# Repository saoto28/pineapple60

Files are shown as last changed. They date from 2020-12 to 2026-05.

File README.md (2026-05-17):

# pineapple60
ergonomic keyboard with Trackpoint

The purposes of this project.
- Install it in ThinkPad

## pineapple-F
Pinapple-Fold, Foldable ergonomic keyboard  
[mockup video on twitter](https://x.com/saoto28/status/2055436990498451473)

## pineapple-D
Pineapple-Deep, under consideration

## p60P
Pineapple60-Popup, installing a Pop-up keyboard on a ThinkPad.  
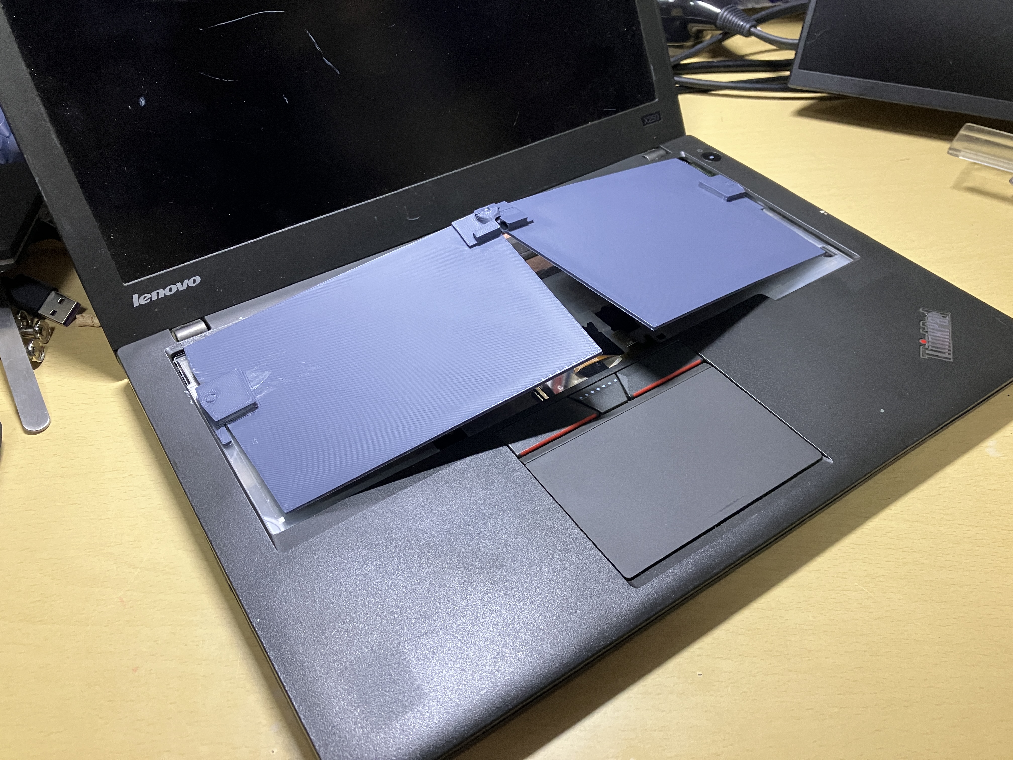
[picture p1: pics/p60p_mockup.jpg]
mockup

[Mockup video](https://youtu.be/z3uHgcyWICA)

## p60C
2026, Pineapple60-Convertible, Three-dimensional ergonomic arrangement and a flat, compact convertible. A patent allowed in Japan.

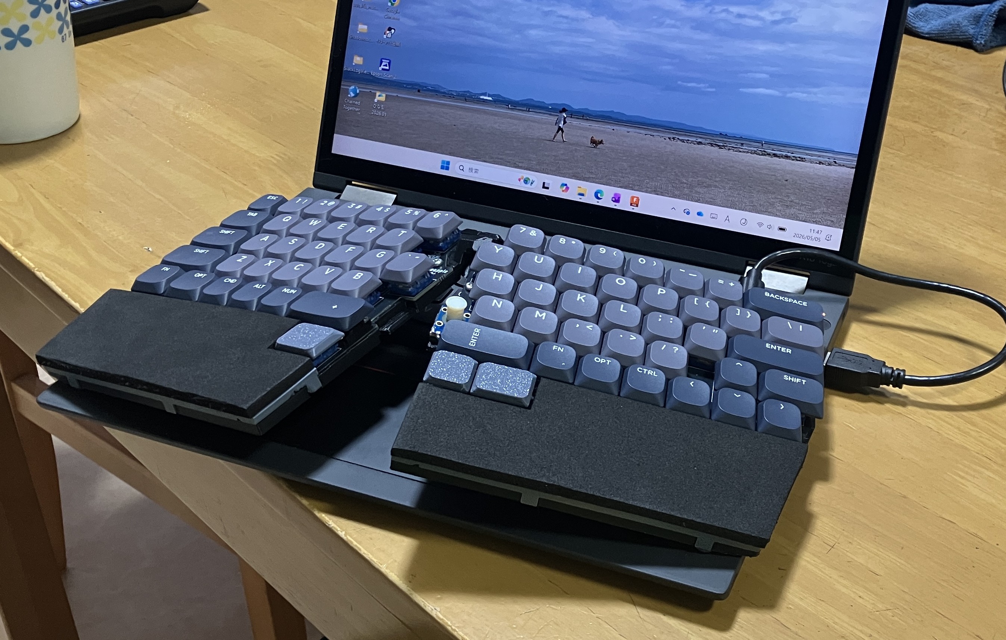
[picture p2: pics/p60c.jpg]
ergonomic mode
1st prototype 
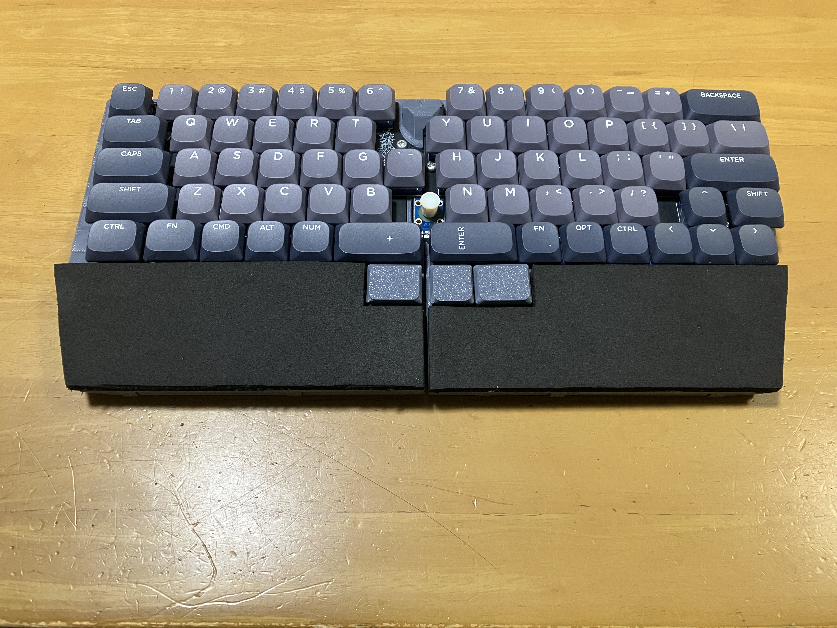
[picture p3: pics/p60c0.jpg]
flat mode

[Video](https://x.com/saoto28/status/2051869687362077159)

Project repository: 
https://github.com/saoto28/pineapple60c.git

## p60S
2025, pineapple60s

Row-Staggered Ergonomic (Alice) keyboard with Kailh PG1316 for installing ThinkPad X13 Gen2

I forgot why it was named "S".

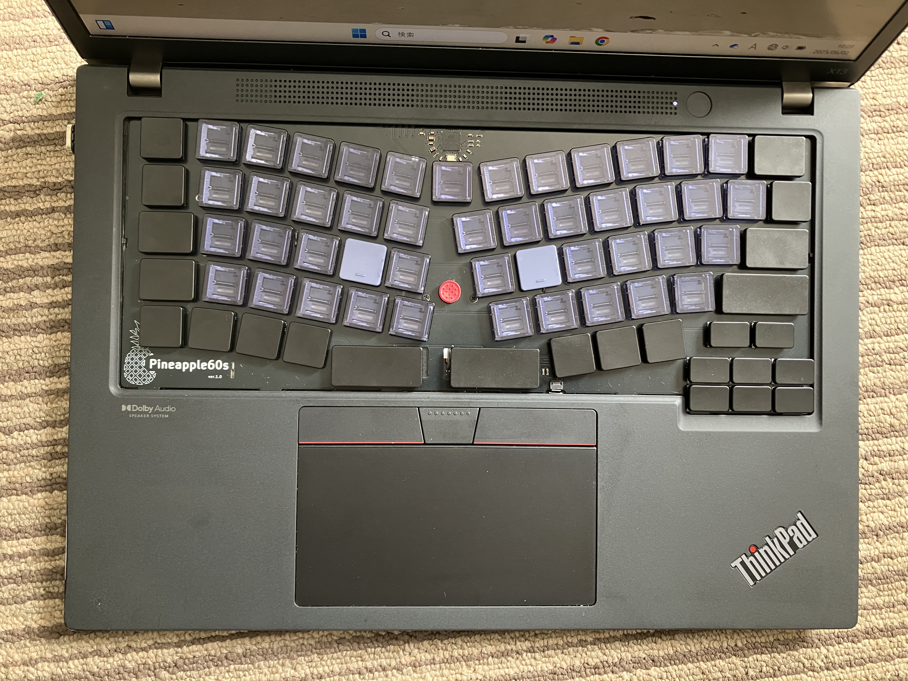
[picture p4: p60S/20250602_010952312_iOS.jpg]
pineapple 60S


For this modification, I chose the target PC for the following reasons:
- It has a Trackpoint
- The keyboard can be easily replaced (the latest ThinkPads are getting difficult)
- The Trackpoint buttons should be on the case, not on the keyboard unit. Otherwise, I would need to attach the buttons to the keyboard I was making.

The following ThinkPads meet the above requirements:
- T440 to T460, and so on
- T460s and T470s
- X13 Gen2 and Gen3

X240 to X270 are also close, but we need to remove the motherboard to remove the keyboard.

Project repository: 
https://github.com/saoto28/pineapple60s.git

How to make (in Japanese): https://note.com/saoto28/n/n716b7ca2e1f9

## p0

Extra edition. Trackpoint module installation.

2021-10 Add the Trackpoint module of ThinkPad X100 on the Microsoft Ergonomic Keyboard.

[How to install the Trackpoint module in the MS ergonomic keyboard](p0/How_to_modify_MS_ergonomic_keyboard.pdf)

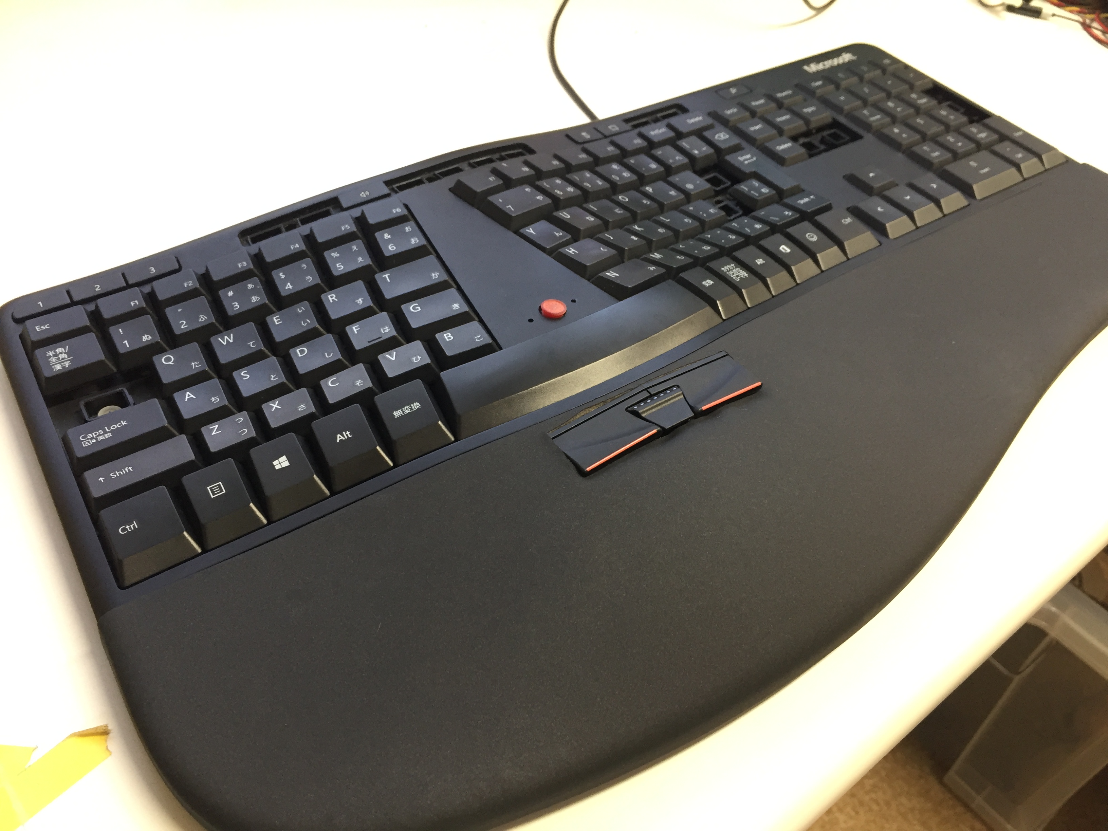
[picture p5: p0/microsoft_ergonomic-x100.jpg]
microsoft_ergonomic


~~## p60X~~

~~Variable key layout board for researching ergonomic keyboard layouts~~

~~< 2021-09 coming soon >~~

## p50V

V-style key layout [board](p50V/README.md)

2021-08 installed on my T470s

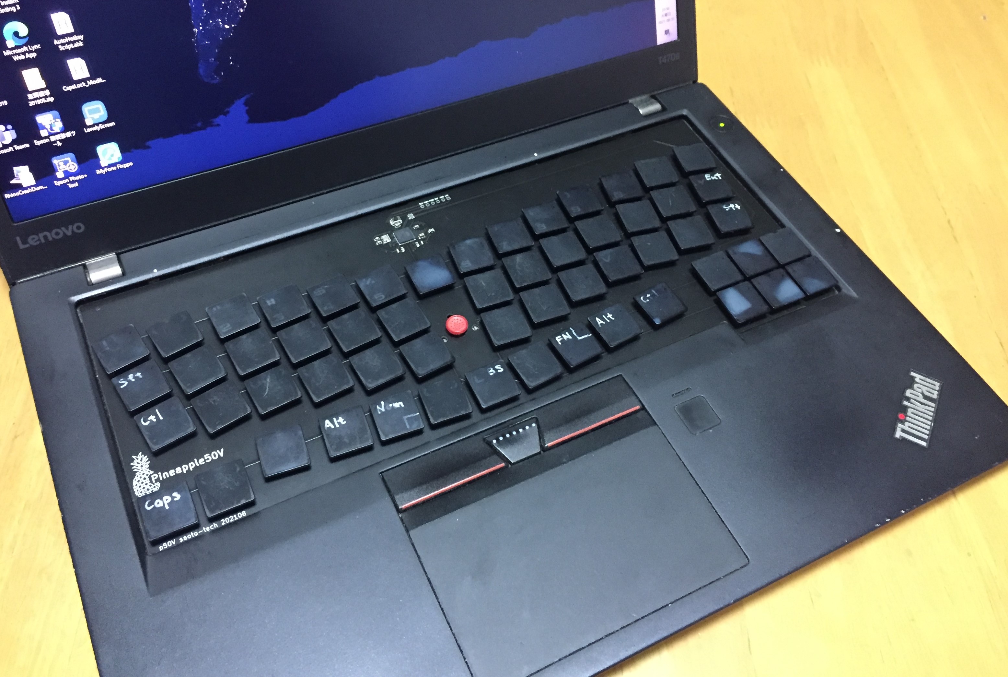
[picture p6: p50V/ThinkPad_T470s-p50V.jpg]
on ThinkPad T470s


## p60-03

third prototype [pcb](p60-03/README.md)

2021-05 p60-03b 

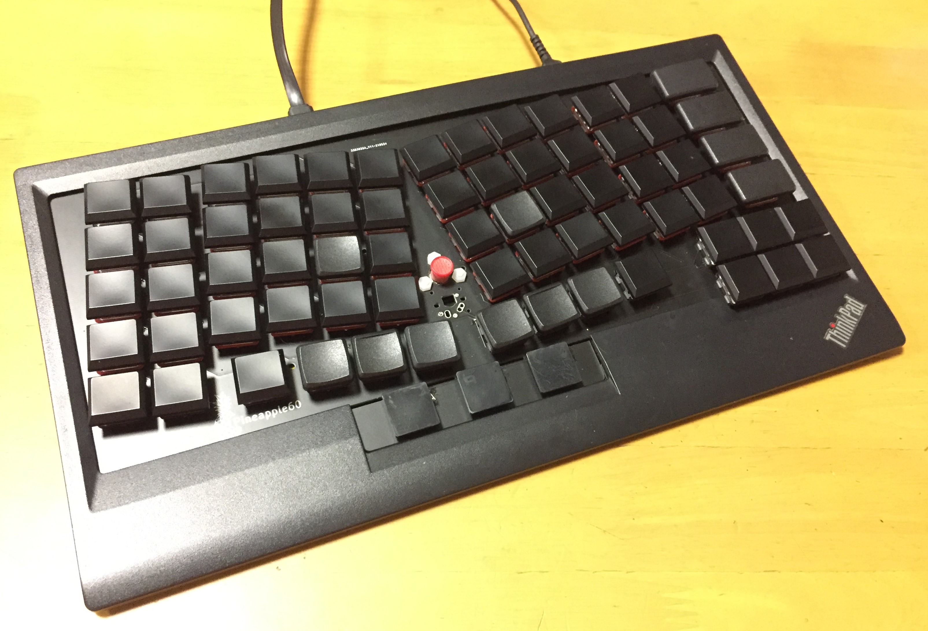
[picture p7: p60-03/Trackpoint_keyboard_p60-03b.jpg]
on Trackpoint keyboard


[how to make the ergonomic Trackpoint keyboard](how_to_make_ergonomic_trackpoint_keyboard.md)

## p4

2021-03 key layout testing [module](p4/README.md)

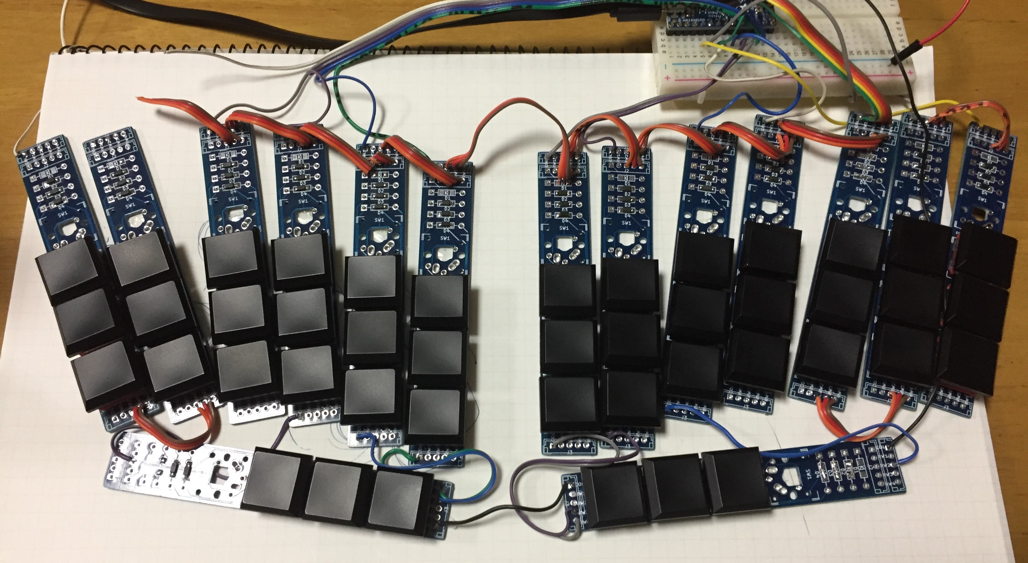
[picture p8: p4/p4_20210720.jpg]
favorite


## p60-02

2020-12 second prototype [pcb](p60-02/README.md)

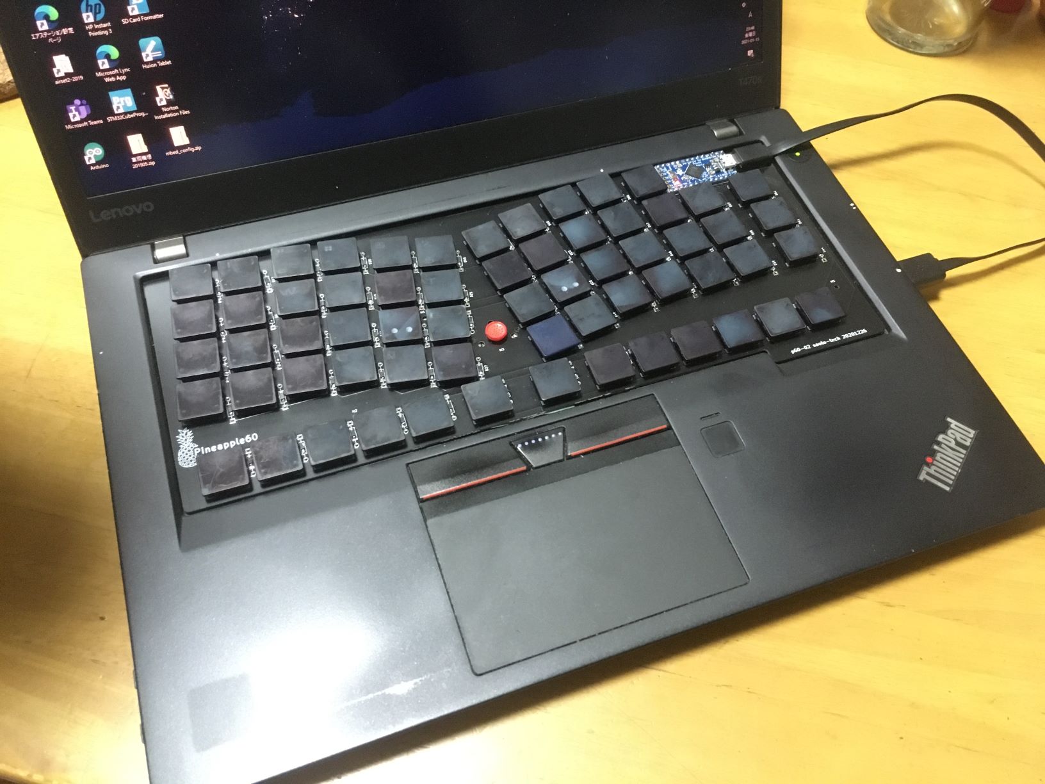
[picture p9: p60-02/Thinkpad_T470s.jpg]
on Thinkpad T470s


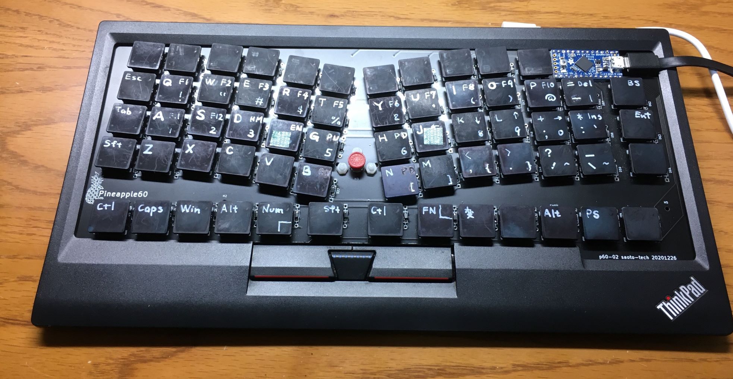
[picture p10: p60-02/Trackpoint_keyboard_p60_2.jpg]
on Trackpoint keyboard


## p60-01

2020-10 first prototype [pcb](p60-01/README.md)

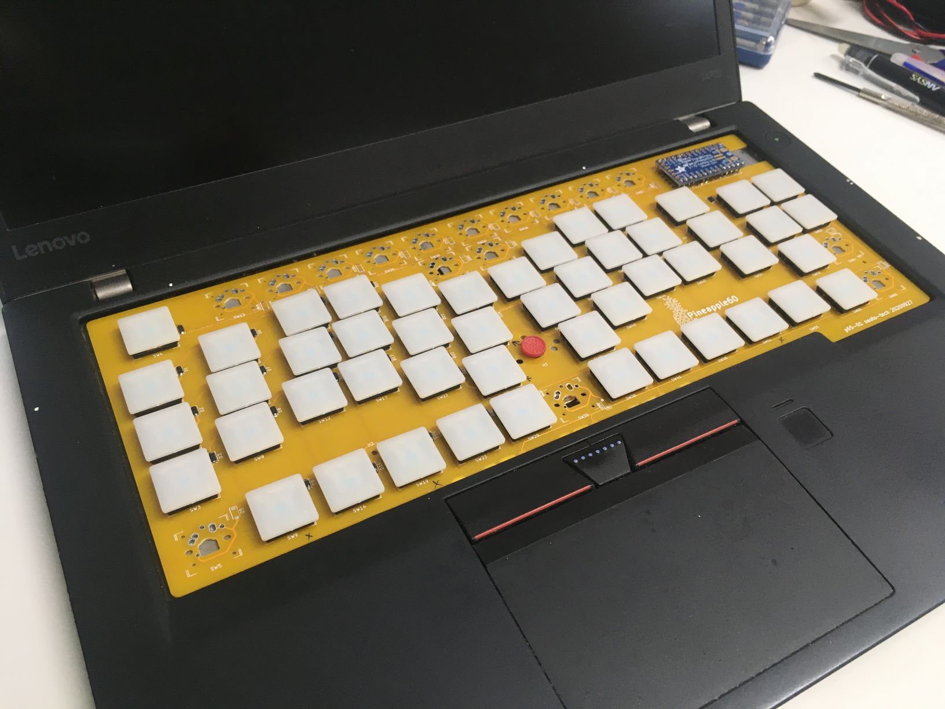
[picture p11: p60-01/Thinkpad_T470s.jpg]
on Thinkpad T470s


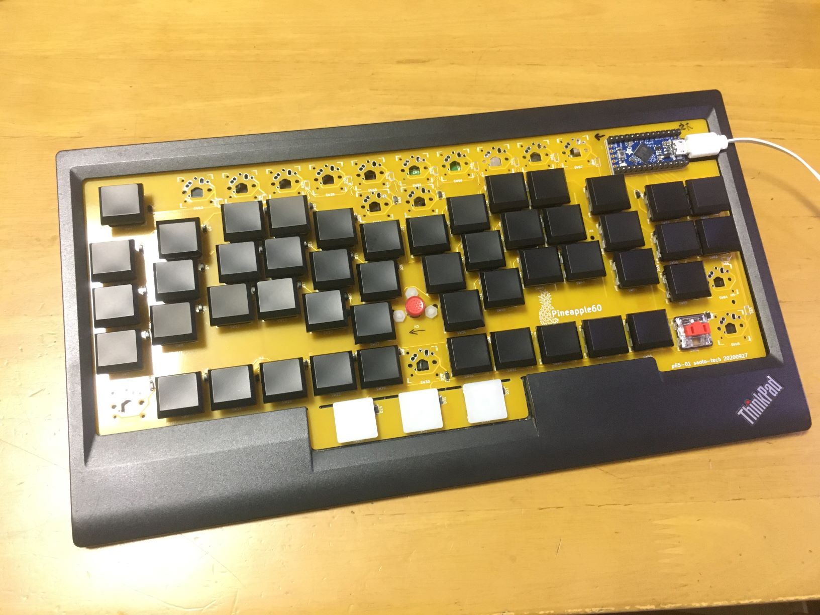
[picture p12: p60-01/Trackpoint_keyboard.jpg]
on Trackpoint keyboard


## pre-pineapple

2020-08 I tried to make an ergonomic keyboard for my ThinkPad T470s, by disassembling and modifying the spare keyboard. But, gave up.

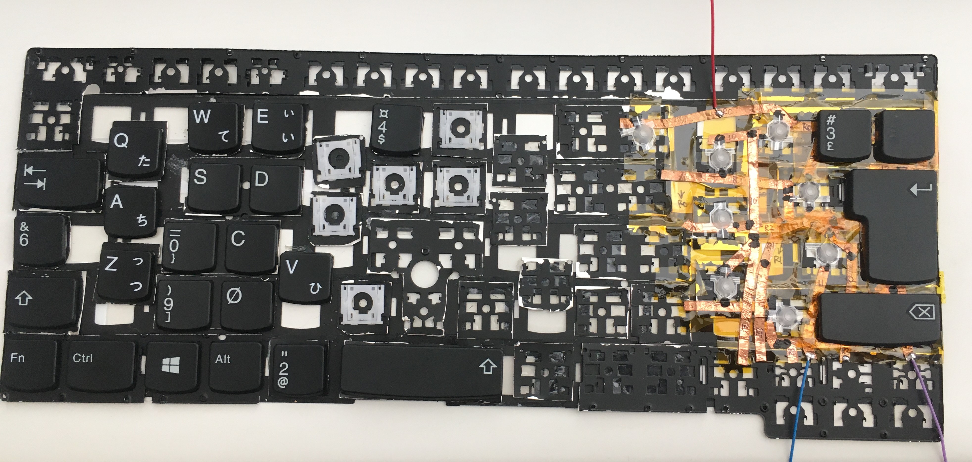
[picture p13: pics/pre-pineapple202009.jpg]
pre-pineapple


## SNS

https://twitter.com/saoto28

https://www.reddit.com/user/saoto28/posts/

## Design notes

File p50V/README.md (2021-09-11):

## p50V
2021-08 V-style layout for ThinkPad T470s

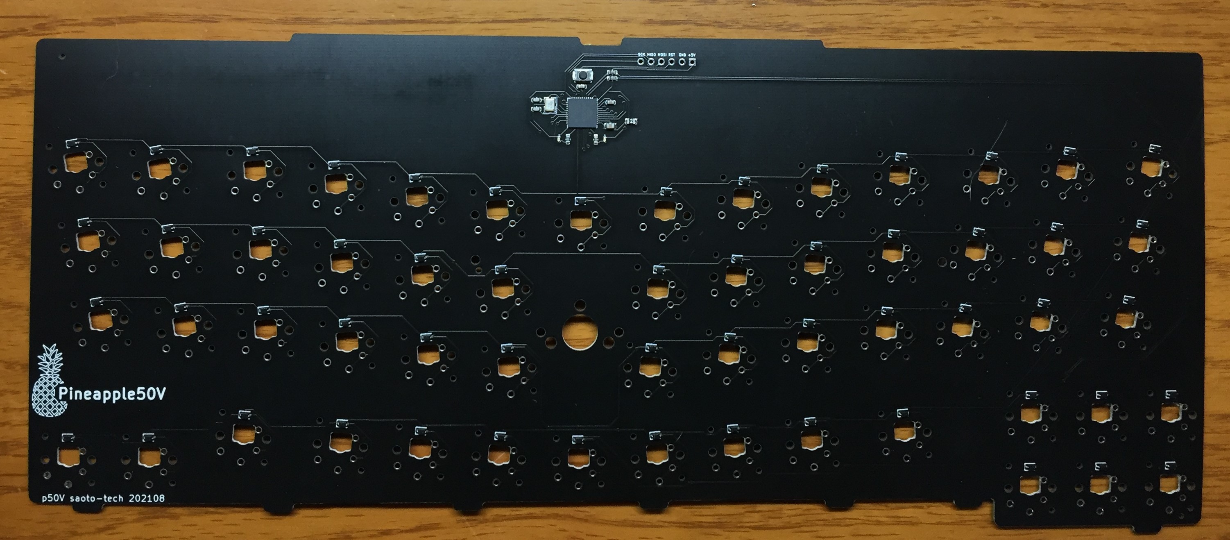
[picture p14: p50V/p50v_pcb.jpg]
PCB


[Schmatic](p50v_sch.pdf)

[PCB](p50v_pcb.pdf)

Features:
- I decided on the V-style layout after testing various layouts with my variable layout keyboard.
- The MCU(Atmega 32u4) is directly installed on the PCB for making it thin. The MCU circuit was referred from the Itsybitsy 32u4.
- Connect the USB line to the port for the smart card reader inside the Thinkpad T470s.

- Give up the top row of key switches because of hitting the frame of the lid. 
- The key switches are the Kailh X-switches that I don't recommend. But, they are the only choice for the laptop.
- Though the key switches are still touching the LCD... I'm using this laptop for mobile.

Issues:
- The Kailh X-switch is not recommended, but no other choice.
- The Kailh X-switches still touch the LCD of the T470s.
- The direction of each key switch was unpopular on Reddit.
- I could flash my app after flashing the bootloader of Itsybitsy, only one time. I'm investigating why.

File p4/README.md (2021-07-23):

## p4
2020-03 key layout testing module
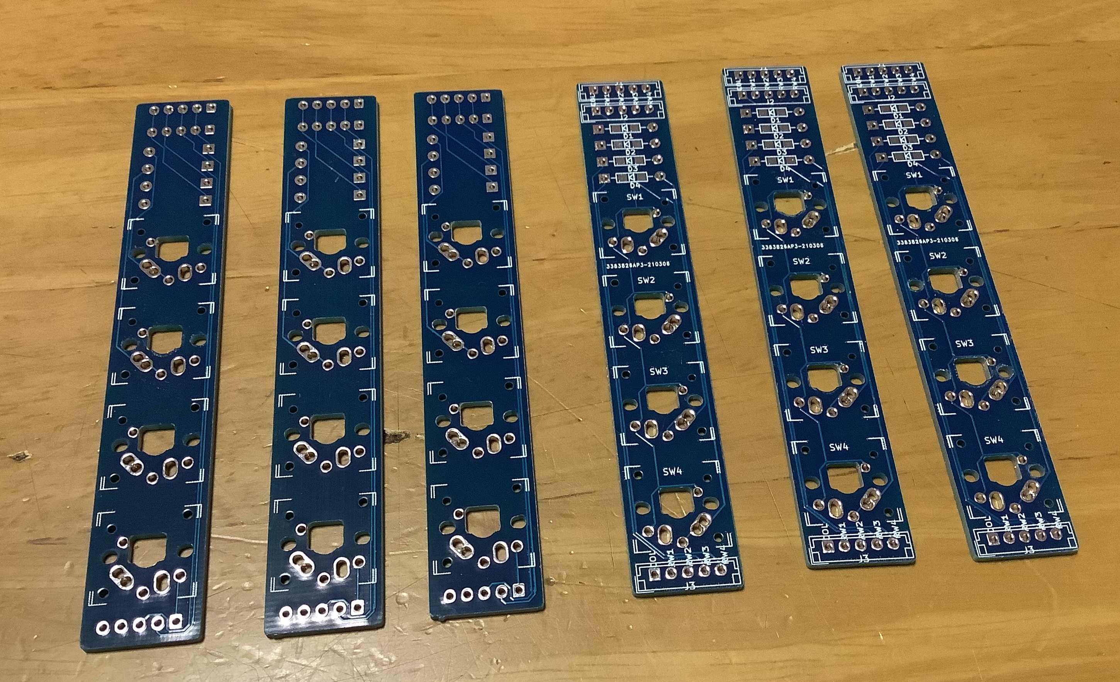
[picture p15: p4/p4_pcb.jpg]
pcb


### X-BOWS like
I feel "T" and "Y" are far from the home position.
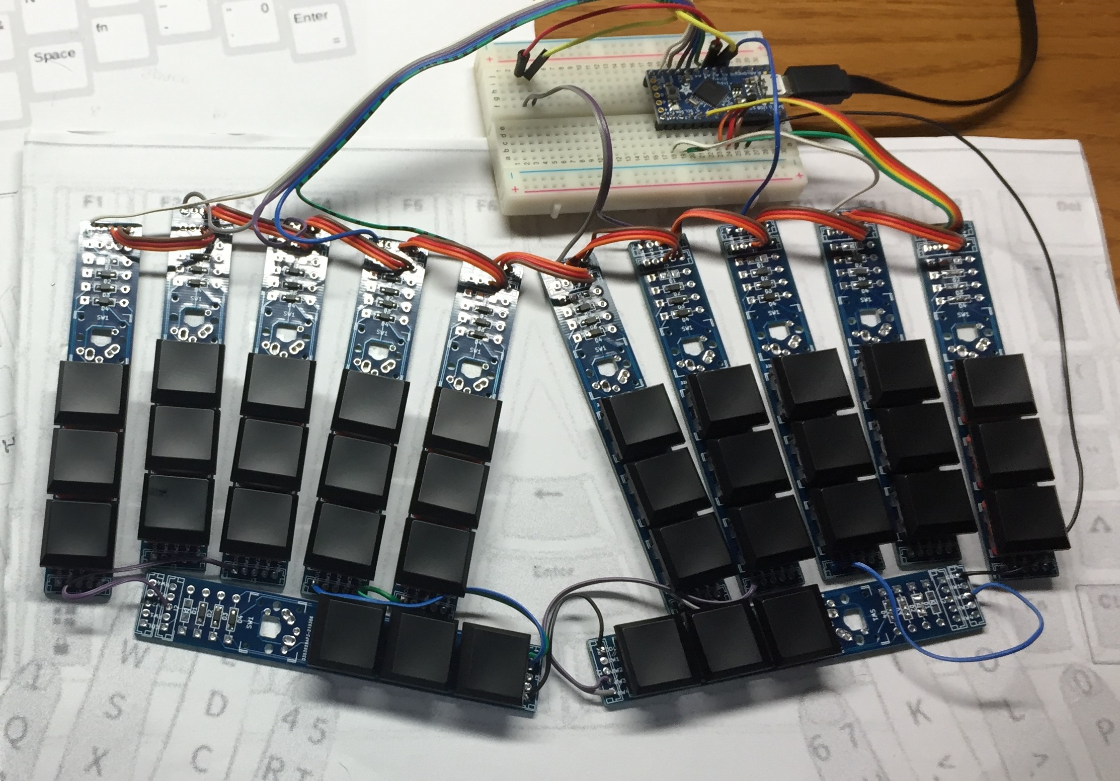
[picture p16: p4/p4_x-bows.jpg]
X-BOWS like


### truly ergonomic like
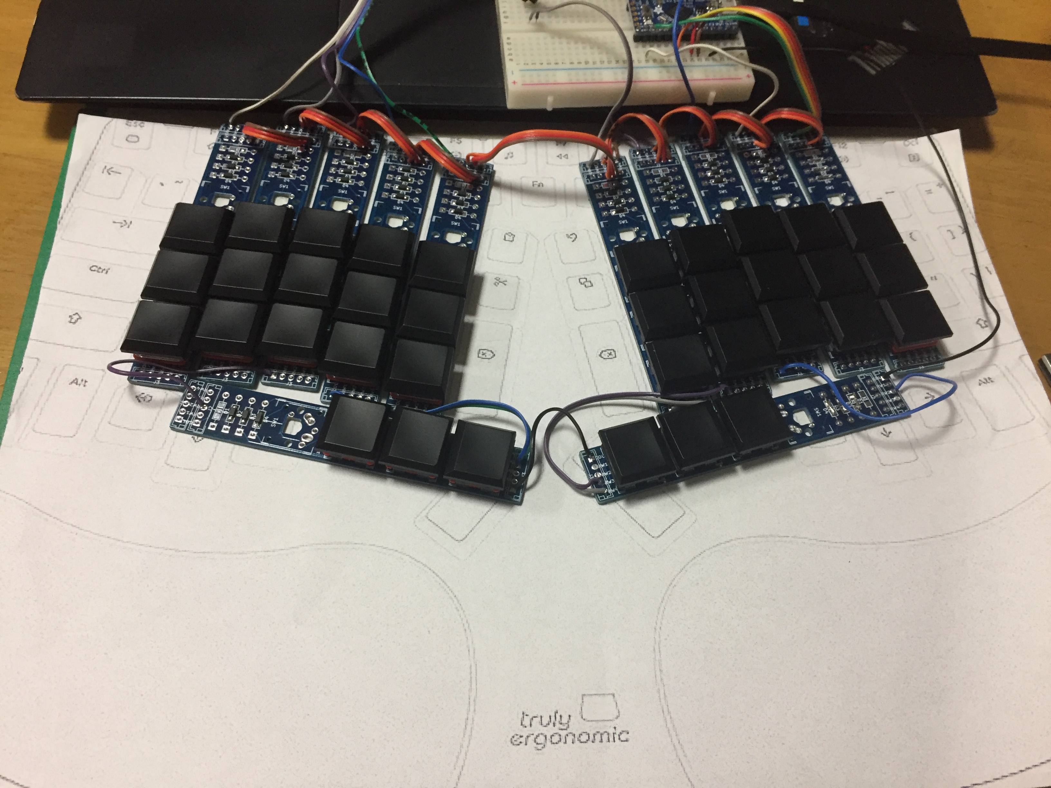
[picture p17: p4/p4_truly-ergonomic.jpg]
truly ergonomic like


### Atreus like
I feel "B" and "N" are far from the home position.
And it is not easy to type "N->I" and "B->E".
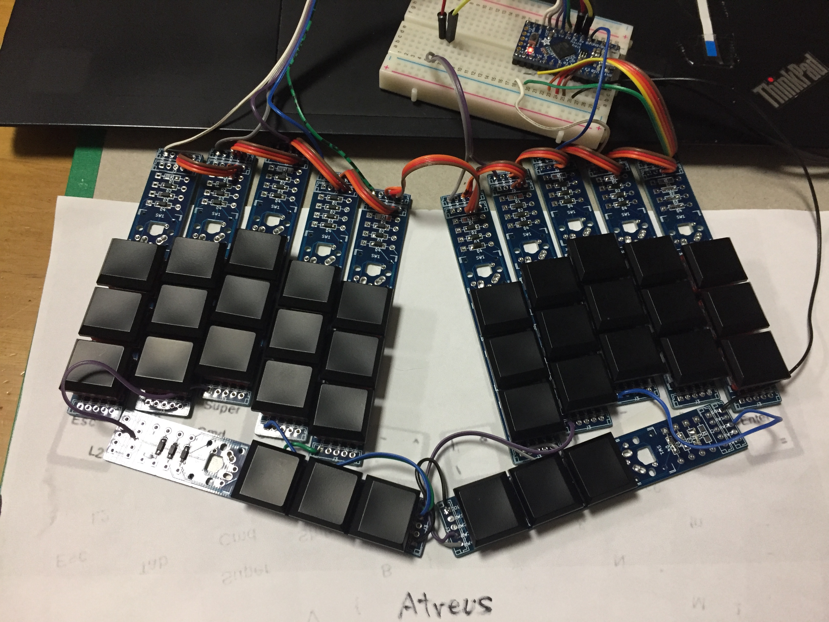
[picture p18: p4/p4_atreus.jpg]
atreus like


### March's favorite
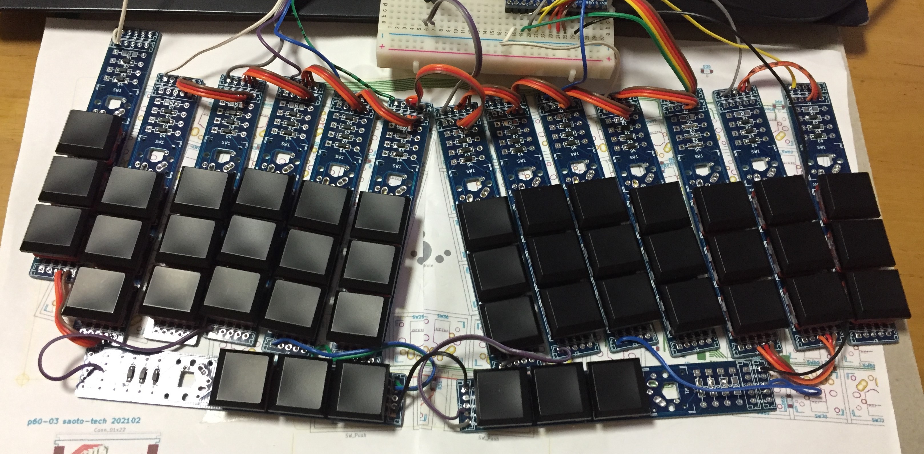
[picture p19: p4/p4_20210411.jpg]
March's


### New favorite - V style
favorite
[How to make V style](How_to_make_the_V-style.pdf)

### Drawing
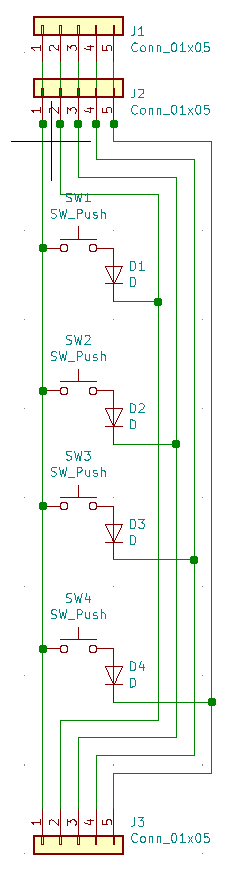
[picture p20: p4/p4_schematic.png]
schematic

layout

### Example wiring connection
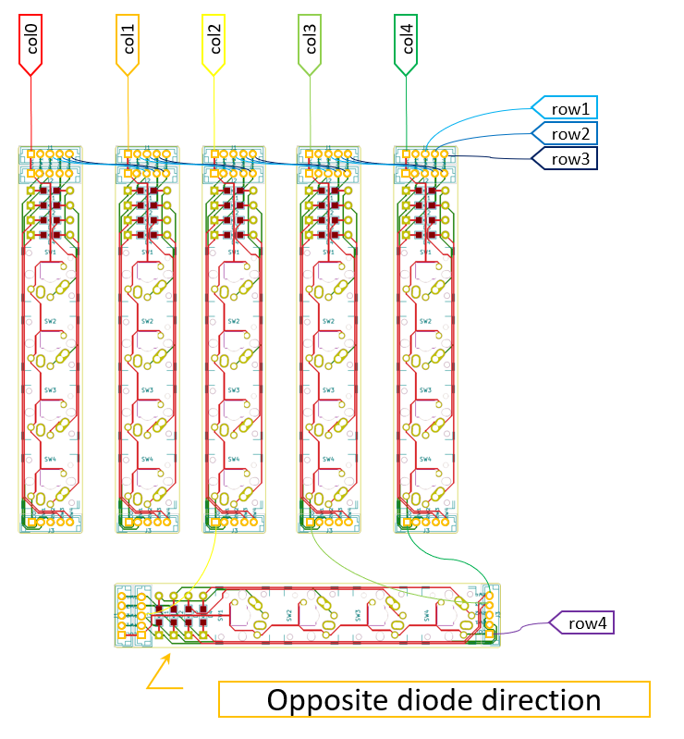
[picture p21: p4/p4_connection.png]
connection


Cut the bottom protrusion of the choc key switches for making them flat.

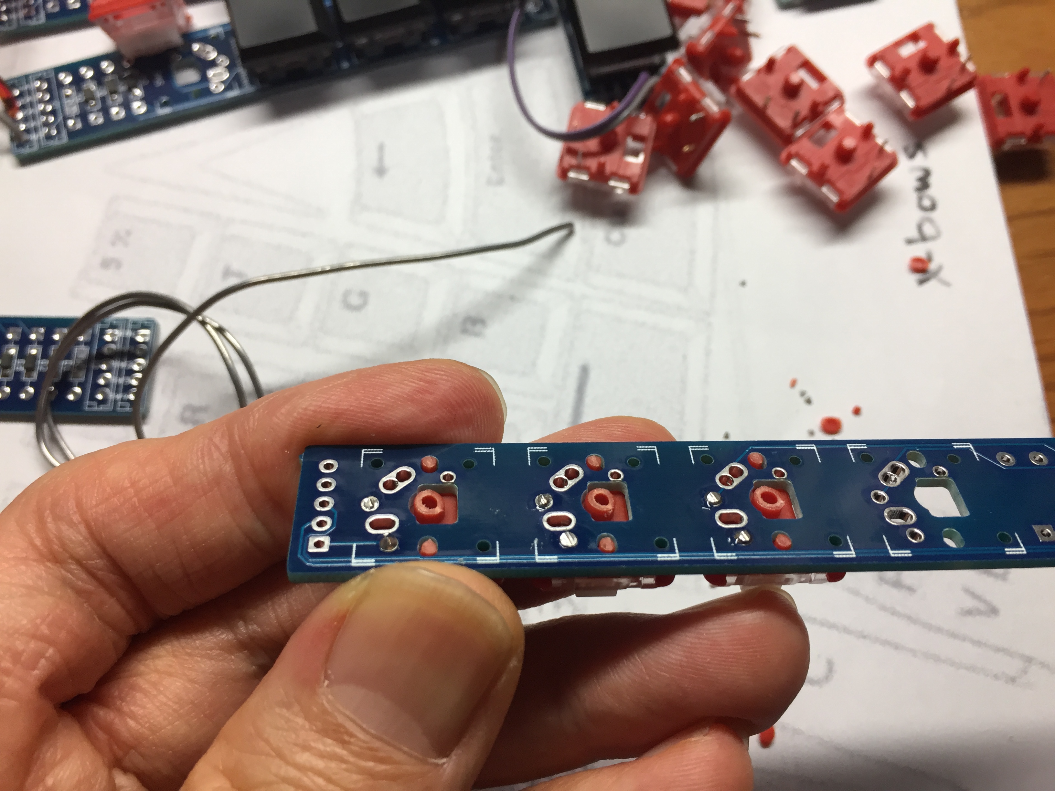
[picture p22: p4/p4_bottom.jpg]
bottom


When Cherry MX or Alps key switches are installed, connect the blue point on the drawing below.

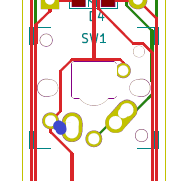
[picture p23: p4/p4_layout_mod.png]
mod


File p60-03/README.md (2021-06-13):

## p60-03b
2021-05 mod of p60-03

Modifications from p60-03:
- Only for installing the Thinkpad Trackpoint Keyboard KU-1255
- Change the THT pads to the SMD pads for the MCU
- Put a center key switch
- Fix some circuits for mouse buttons
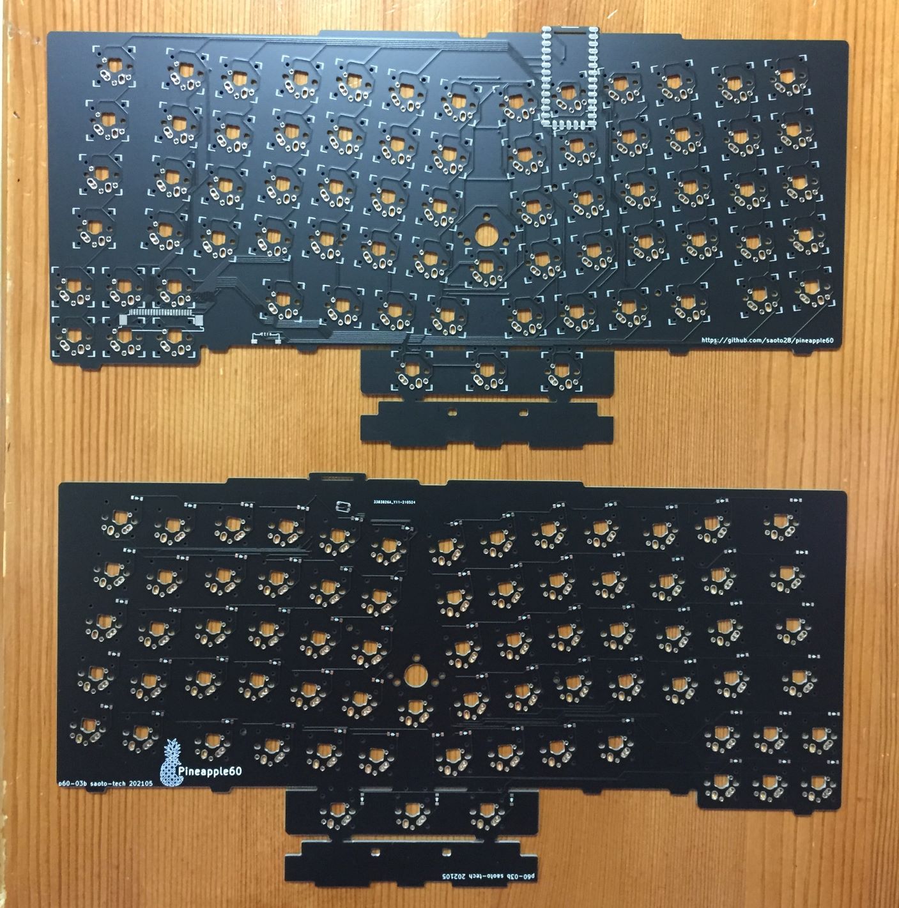
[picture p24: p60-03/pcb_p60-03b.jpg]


[Schmatic](p60-03b_sch.pdf)

[PCB](p60-03b_pcb.pdf)

## p60-03
2021-04 third prototype pcb

Features
- For installing the Thinkpad T470s or Thinkpad Trackpoint keyboard KU-1255
- The MCU is Adafruit itsybitsy 32u4. It is put backside of the PCB for the Trackpoint keyboard, or put on an additional small plate fot the Thinkpad. 
- Compatible key switches: 
Kailh choc and X-switch, MX(unconfirmed), and ALPS(unconfirmed)
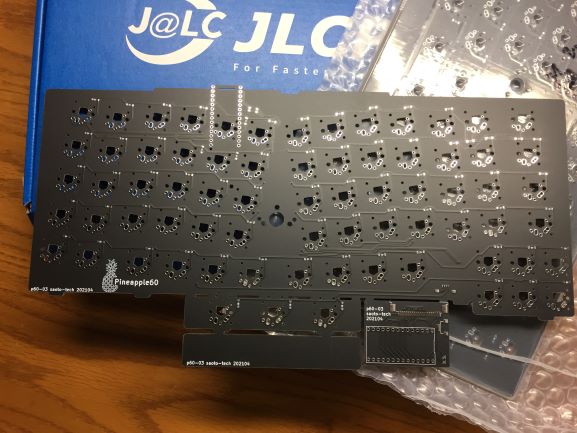
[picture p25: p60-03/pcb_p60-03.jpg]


with Kailh choc switches
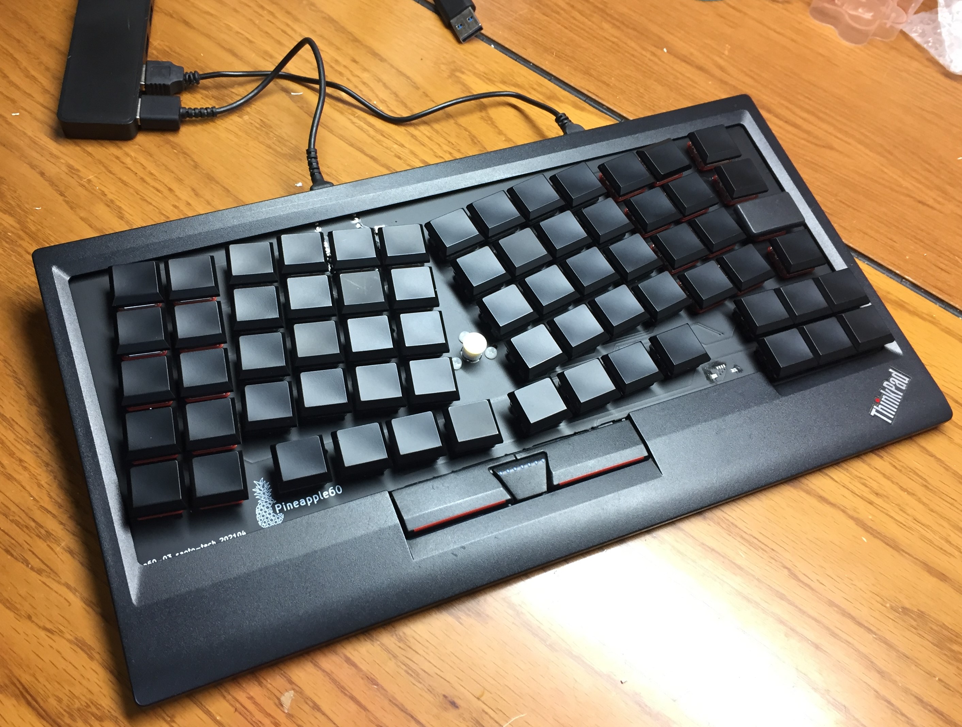
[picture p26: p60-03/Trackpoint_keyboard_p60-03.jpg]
on Trackpoint keyboard


with Kailh x-switches
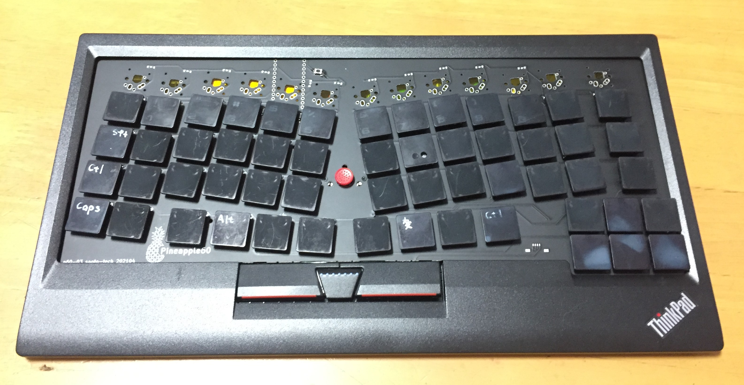
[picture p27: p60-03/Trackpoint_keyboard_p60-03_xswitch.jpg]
on Trackpoint keyboard


Modifications from p60-02:
- Modify the key layout according to trial results on p4 pcb 
- Put arrow keys
- Move the MCU backside for the Trackpoint keyboard
- Move the MCU to an additional small pcb for the Thinkpad
- Connect the USB line inside the Thinkpad through the small pcb

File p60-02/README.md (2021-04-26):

## p60-02
2020-12 second prototype pcb
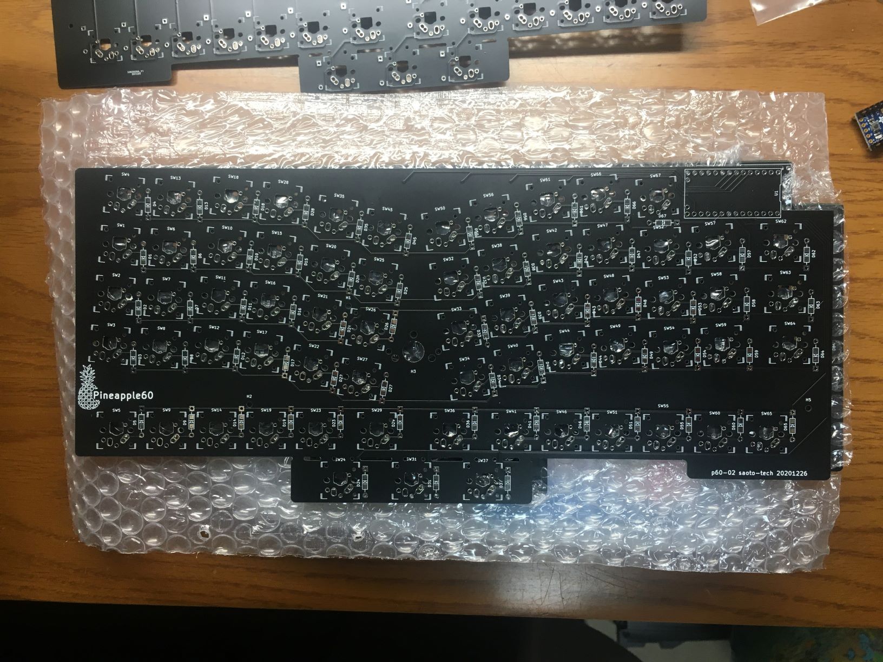
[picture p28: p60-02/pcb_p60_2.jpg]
PCB


Modifications from p60-01:
- Tilt the key layouts
- Less deformation from ortho-keyboard
- Move the Trackpoint position and MCU position

Current concerns :
- USB connection inside ThinkPad (for the Ergo ThinkPad)

- ~~Connection with the Trackpoint module (for the Ergo Keyboard)~~
- Combine the two USB connections between new board and original board (for the Ergo Keyboard)

[Schmatic](p60-02_sch.pdf)

[PCB](p60-02_pcb.pdf)

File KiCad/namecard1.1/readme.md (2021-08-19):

# KiCAD format for the Arduino shield  namecard ver.1.1

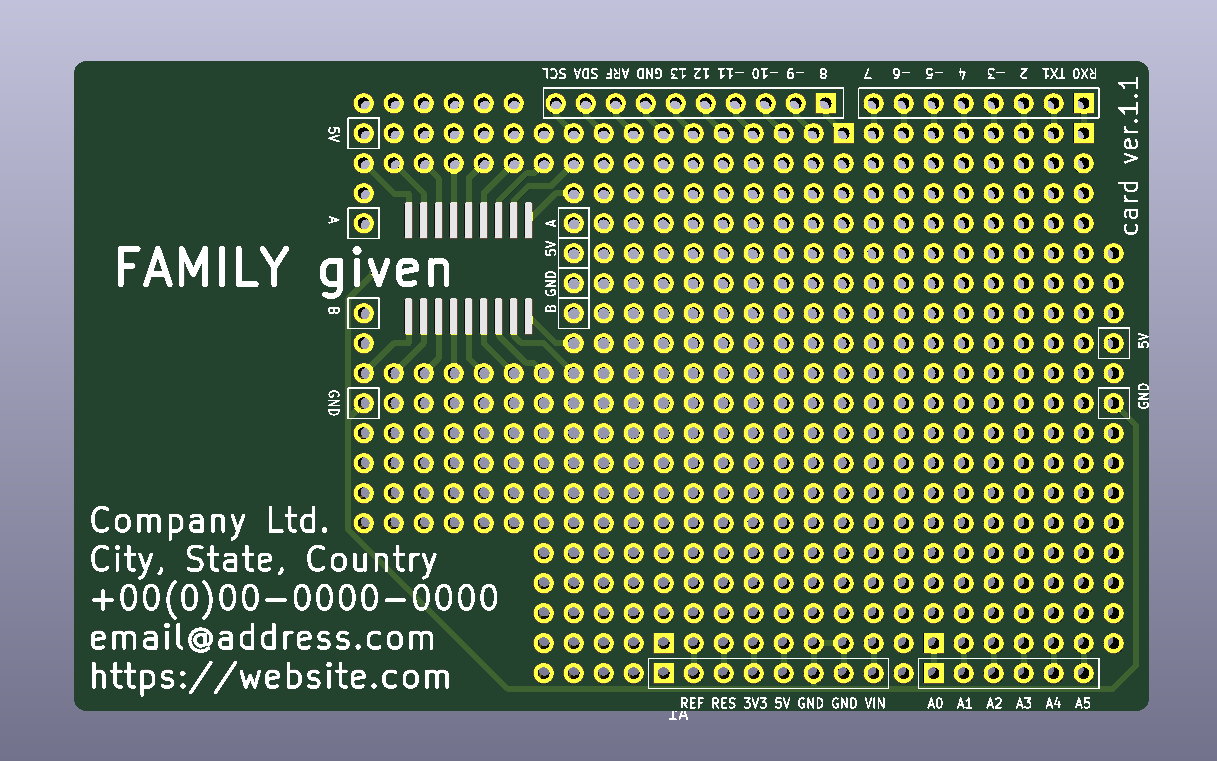
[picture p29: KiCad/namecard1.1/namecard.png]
namecard


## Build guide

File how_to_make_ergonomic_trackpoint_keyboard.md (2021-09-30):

# How to make the ergonomic Trackpoint keyboard with P60-03b

1. [Parts list](#sec1)
1. [Side view](#sec2)
1. [Assemble the board](#sec3)
1. [disassemble the Thinkpad Compact keyboard](#sec4)
1. [Use the original mouse button switches of the Thinkpad keyboard](#sec5)
1. [When you don't use the original mouse button switches](#sec6)
1. [Install the keyboard in the case](#sec7)
1. [Install the software](#sec8)

## 1. Parts list

- Base keyboard: Lenovo ThinkPad Compact USB Keyboard with TrackPoint [KU-1255/0B47190](https://support.lenovo.com/us/en/solutions/pd026745-thinkpad-compact-usb-keyboard-with-trackpoint-overview-and-service-parts) x 1 pcs

    (You can not install this PCB in the Bluetooth Keyboard [KT-1255], because the MCU position was used for the battery.)

- PCB: [Pineapple60-03b](https://www.etsy.com/shop/SaotoTech) x 1 pcs
- MCU: Adafruit [ItsyBitsy 32u4](https://learn.adafruit.com/introducting-itsy-bitsy-32u4) - 5V x 1 pcs

    (3.3V type is not usable. Because the #5 pin is a special output-only pin.)
- Key switches: Kaih [choc](https://www.kailhswitch.com/mechanical-keyboard-switches/low-profile-key-switches/linear-mechanical-keyboard-switches.html) x 68 pcs

    (The choc is higher than the original key switch. The Kailh [X Switch](https://www.kailhswitch.com/mechanical-keyboard-switches/low-profile-key-switches/thin-notebook-mechanical-key-switch.html) is similar height as the original. But, expensive)
- Keycaps x68 pcs
- SMD Diodes: 1N4148W or similar SOD123 type x 68 pcs
- Reset switch: C&K [KMR211NG LFS](https://www.digikey.com/en/products/detail/c-k/KMR211NG-LFS/2176494) or compatible x 1 pcs

- bolts and nuts for fixing the Trackpoint module: M2.5 x 3mm x 3 sets
- Trackpoint cap: by [Saoto-Tech](https://www.etsy.com/shop/SaotoTech) (optional) x 1pcs
- etc: Kapton tape, double-sided tape, solder 

When you don't use the original mouse button switches,
- additional key switches: Kailh chocs or X-switches w/caps x 3 pcs
- FFC connector:  	Würth Elektronik  [686104183522](https://www.digikey.jp/product-detail/en/w%C3%BCrth-elektronik/686104183522/732-11326-1-ND/7087352) or compatible x 1 pcs
- FFC cable: [4pos, 1.0mm pitch, more than 115mm length](https://www.digikey.jp/product-detail/en/molex/0152670709/WM22903-ND/4427461) or Compatible x 1 pcs

## 2. Side view

### with Kailh choc switches
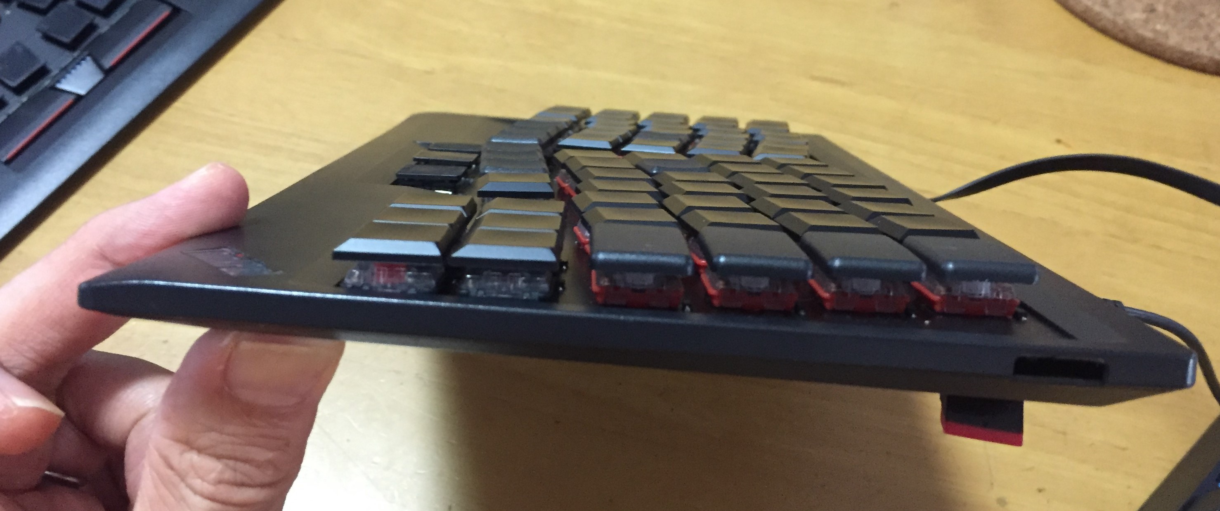
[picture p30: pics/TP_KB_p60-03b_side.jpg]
side


### with Kailh X-switches
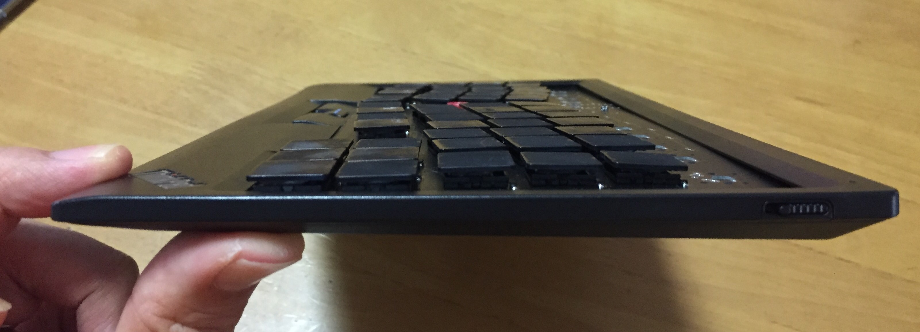
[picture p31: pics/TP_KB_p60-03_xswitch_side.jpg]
side


## 3. Assemble the board

Cut the pcb. 
If you don't use the original mouse button switches of the keyboard, don't remove the base plate of three mouse switches. 
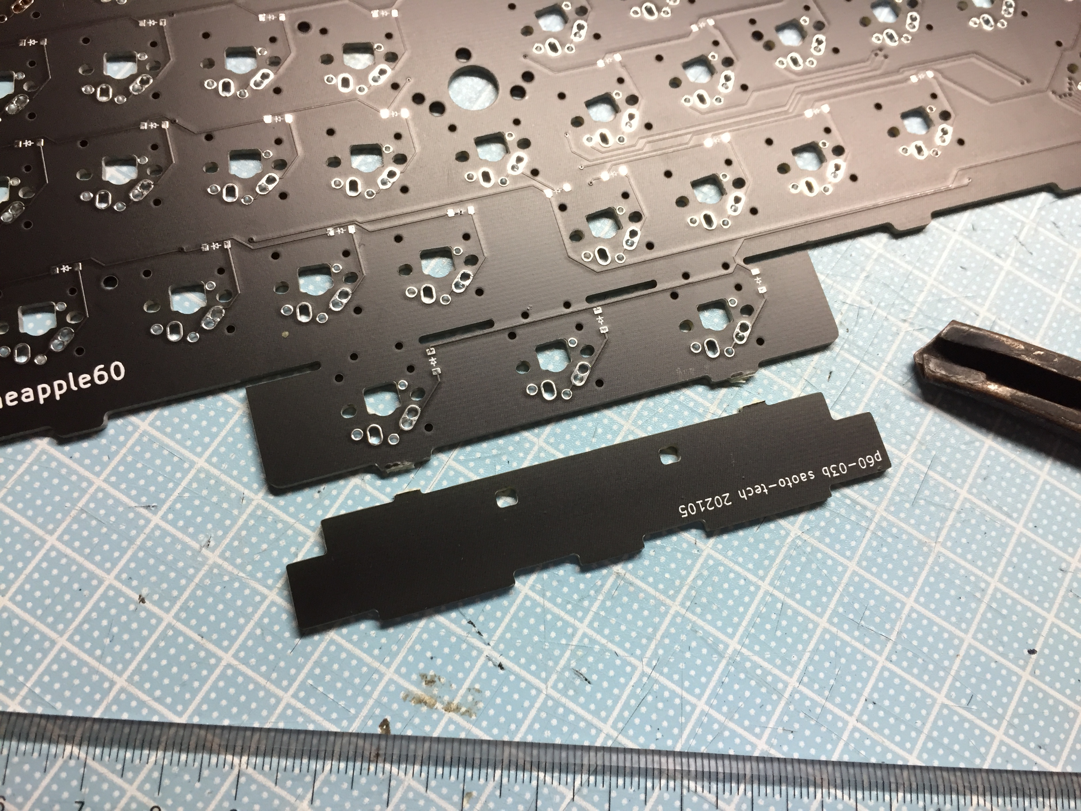
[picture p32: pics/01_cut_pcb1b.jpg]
See here

When you use the original mouse switches of the keyboard, remove the base.
(But, using the original mouse switches is quite troublesome. See this how-to at first)
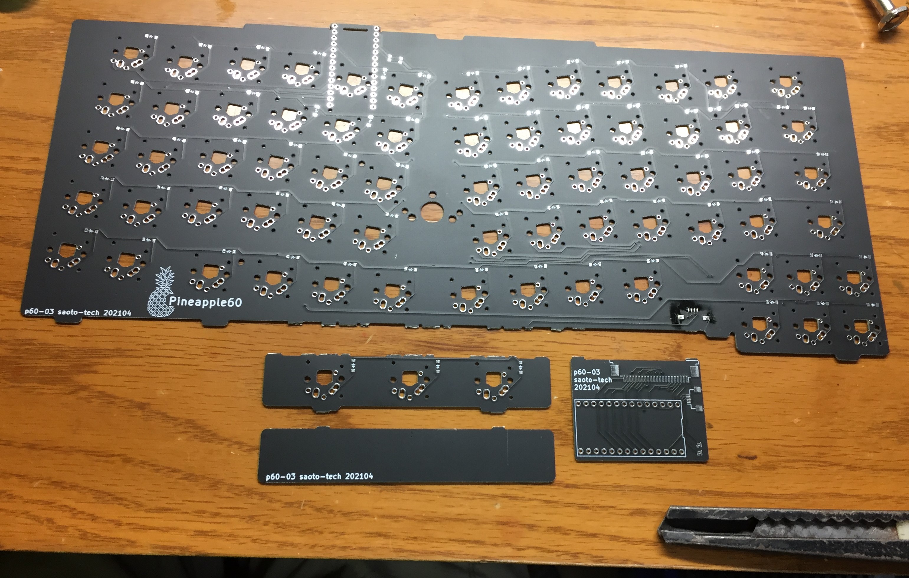
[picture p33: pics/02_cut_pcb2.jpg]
cut_pcb
(This pic is p60-03)

### How to put the diodes.

(1)Put some solder on one side.

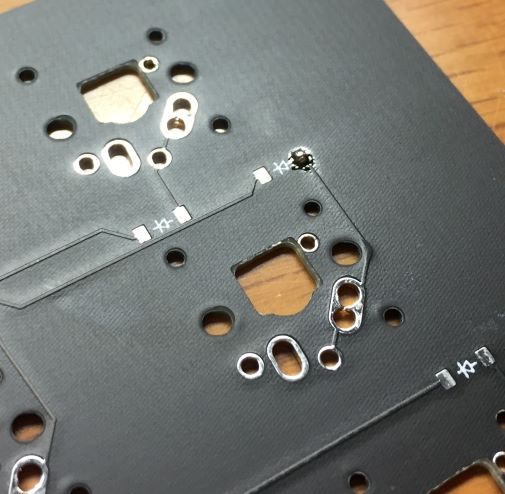
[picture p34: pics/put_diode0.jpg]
put_diode0


(2)Solder one side of the diode. Attention the orientation.

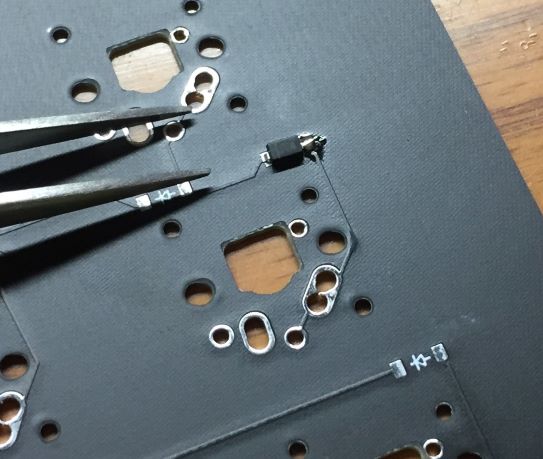
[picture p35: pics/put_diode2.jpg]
put_diode2


(3)Solder another side of the diode.

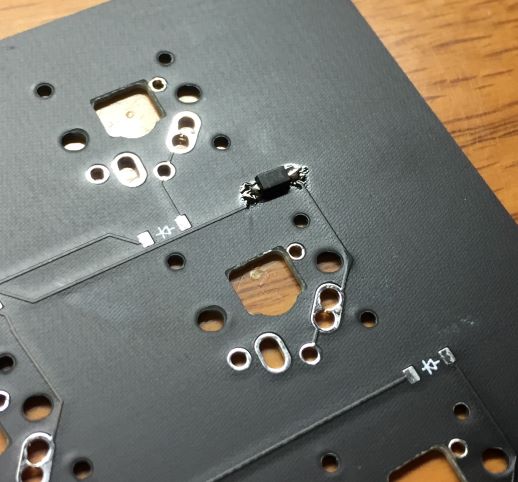
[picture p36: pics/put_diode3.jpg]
put_diode3


### How to put the key switches.

(1)Solder

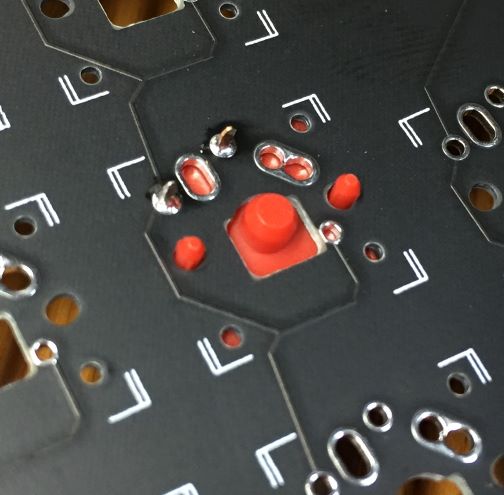
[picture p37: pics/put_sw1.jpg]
put_sw1


(2)Cut all protrusions. In this time, push the key switch fully. Otherwise,  the cut surface is deformed.
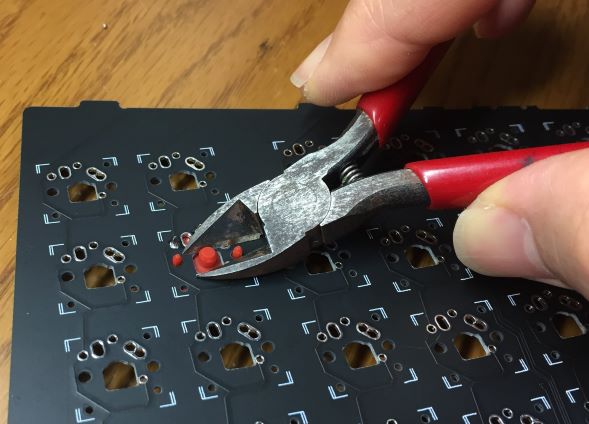
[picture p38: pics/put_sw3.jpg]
put_sw3


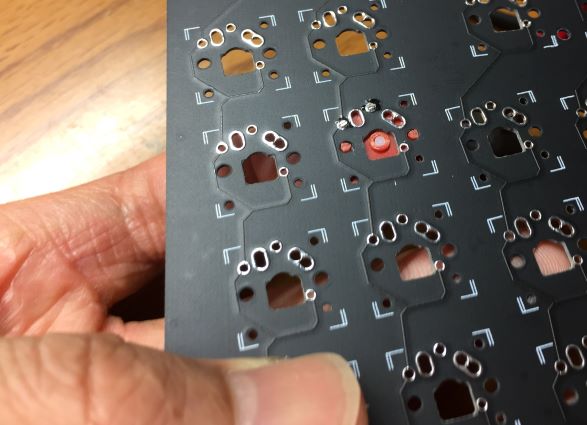
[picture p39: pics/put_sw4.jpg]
put_sw4


### How to put the MCU

put a key switch on "R" position that is the MCU position.

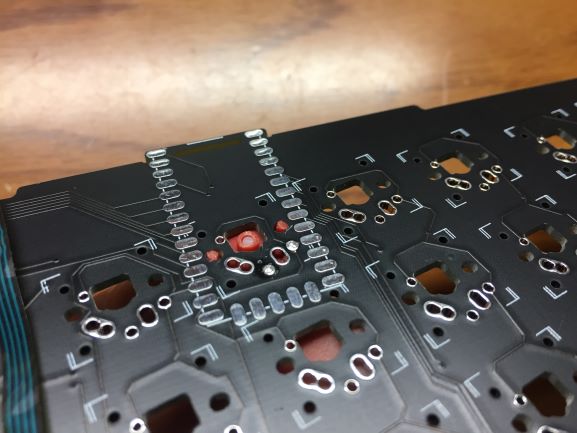
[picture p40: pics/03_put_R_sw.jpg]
put a key switch on "R"


Attention: It is very difficult to exchange the key switch after putting the MCU. Make the key switch connection sure.

Put insulating tape on the back side. And put some solder on a pad of the MCU.

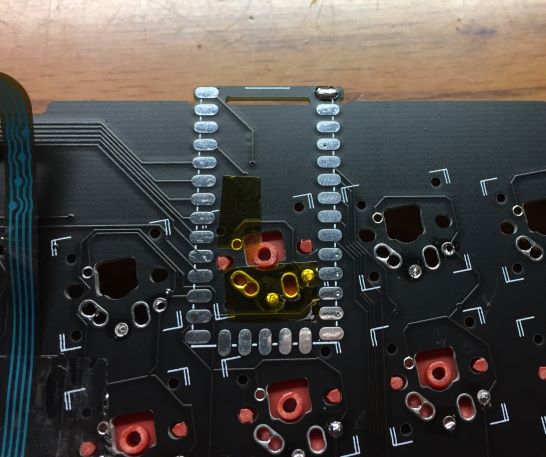
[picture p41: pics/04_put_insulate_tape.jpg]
insulate tape


Put the MCU, and solder the pad.

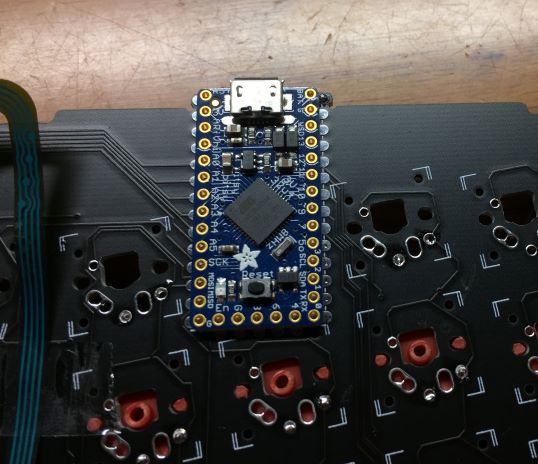
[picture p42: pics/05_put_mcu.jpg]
solder MCU


(This pic shows 32u4 - 3V type that is not usable.)

After soldering all pads, you should check all connections by the tester. Actually, we don't need bottom 5 pad connections.

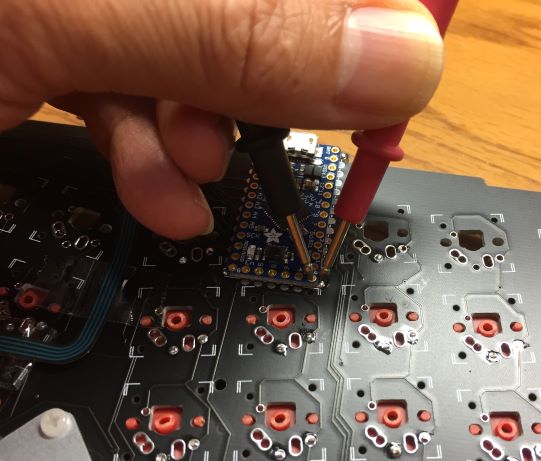
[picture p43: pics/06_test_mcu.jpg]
test


Put a reset switch

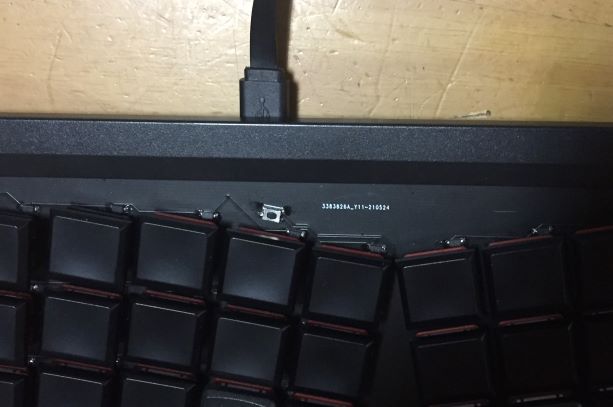
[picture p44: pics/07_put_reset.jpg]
reset


At last,

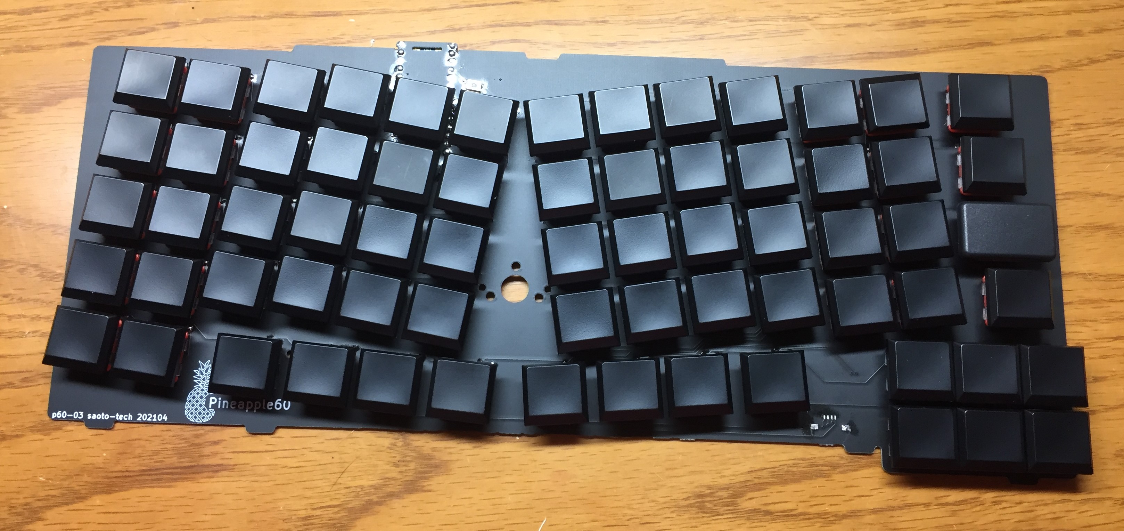
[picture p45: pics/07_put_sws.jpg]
put sws

(It is ver. p60-03)

ver. p60-03b has a footprint for the center key switch. When putting the key switch, it is necessary to modify the keycap to avoid interference with the Trackpoint.

## 4. disassemble the Thinkpad Compact keyboard

(ref: from 7:30 of https://www.youtube.com/watch?v=dql8XsqlqxE)

Open the Trackpoint keyboard. Just pull up the frame. I feel The front center part is easy to come off.
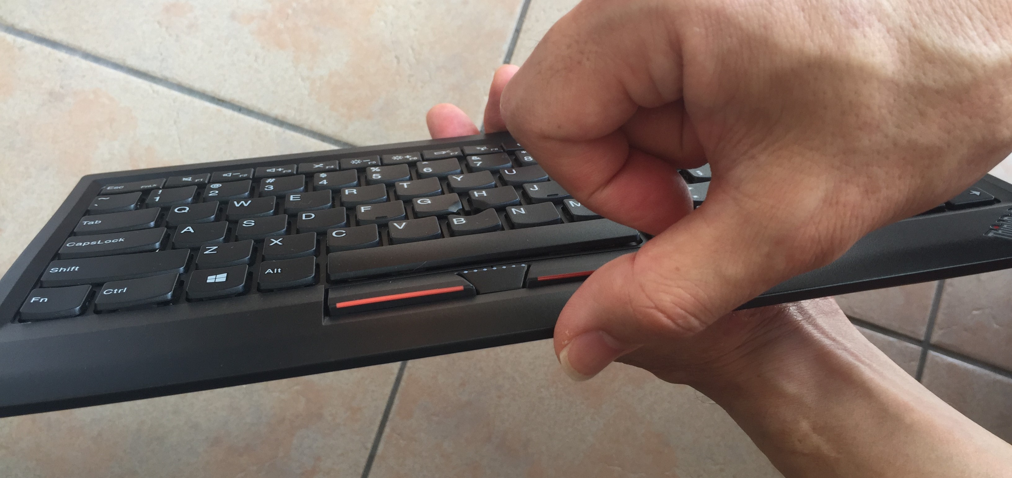
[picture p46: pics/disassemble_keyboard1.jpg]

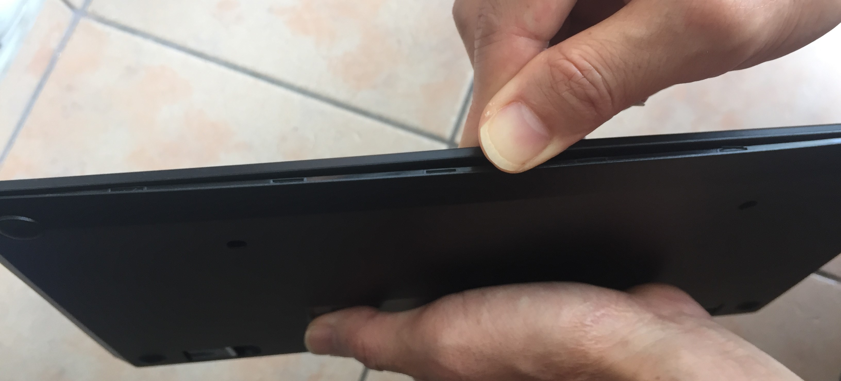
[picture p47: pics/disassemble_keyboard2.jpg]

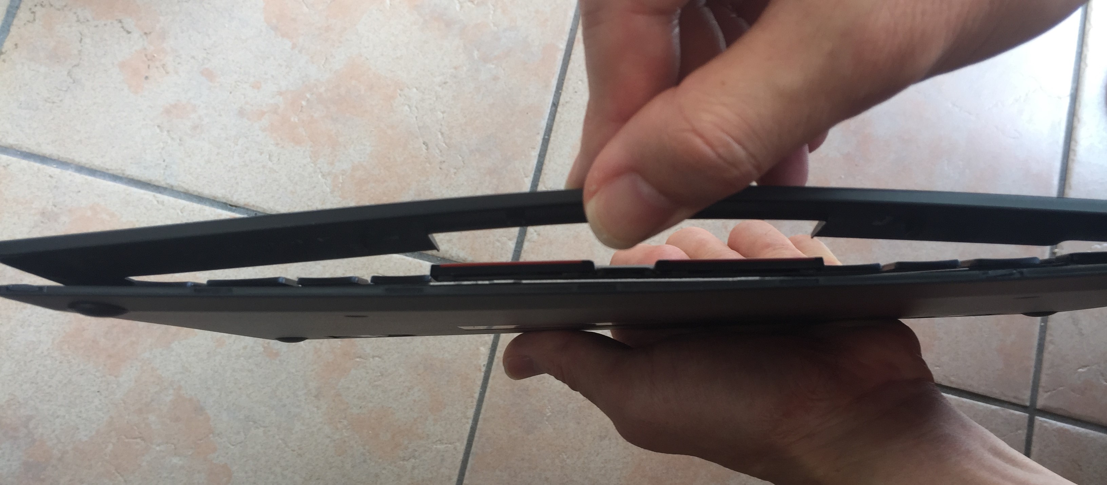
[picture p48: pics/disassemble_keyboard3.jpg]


Remove the keyboard plate. It's just glued, but strongly. The plate can be peeled off, though it is very hard. 
Don't forget to disconnect the FFC cable early on.
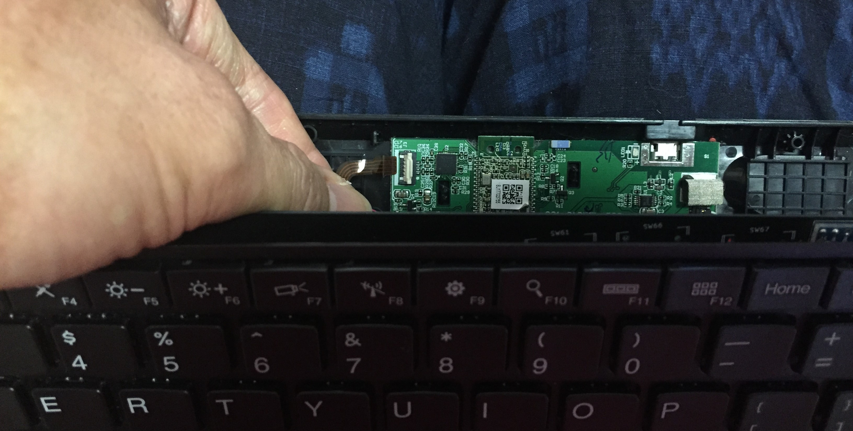
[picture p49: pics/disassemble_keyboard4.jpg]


Remove the Trackpoint module from the keyboard plate.

If you like, attach the steel plate weight on the back of the keyboard to the case. 

## 5. Use the original mouse button switches of the Thinkpad keyboard
If you want to use the original mouse button switches, you have to break the keyboard here, and it is quite troublesome.  (If you don't want to do, go to "[When you don't use the original mouse button switches](#sec6)".)

(1)At first, pull off the separator plate(?) excluding the mouse button part. It is just pulled off. 
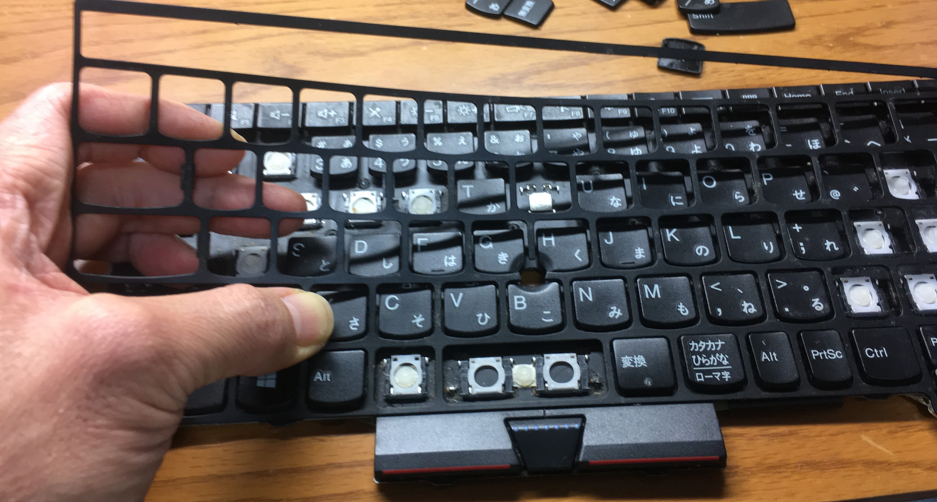
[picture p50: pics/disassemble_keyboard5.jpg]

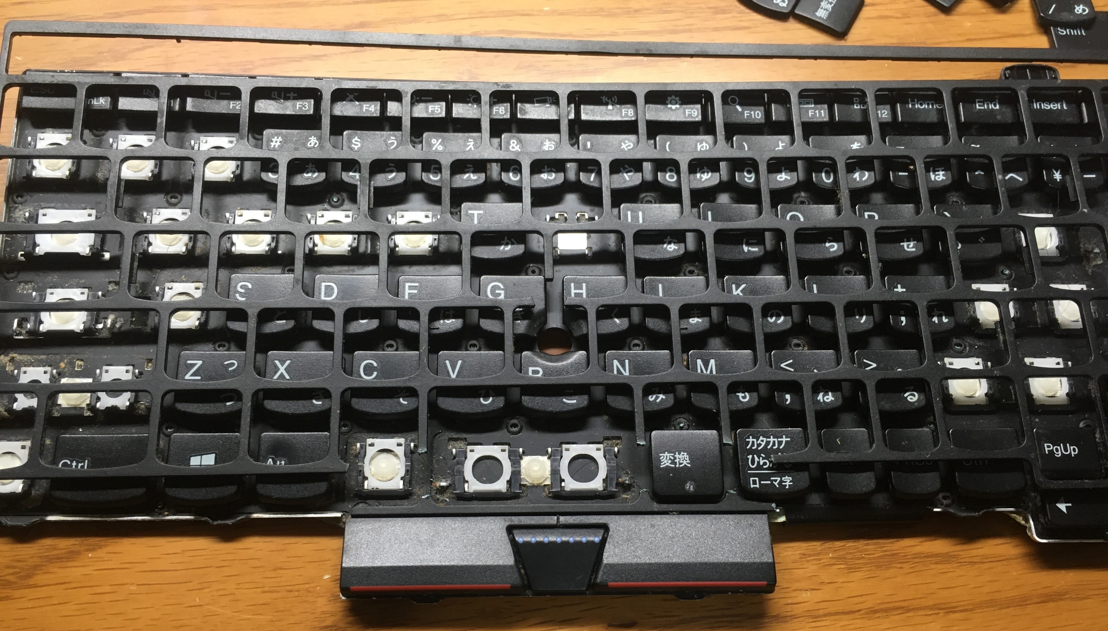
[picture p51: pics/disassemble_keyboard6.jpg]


(2) Pull off the keycaps. Basically, it can be pulled from the upper excluding some keys that are "G", "H", "B", Arrow keys, Return key, and function keys.
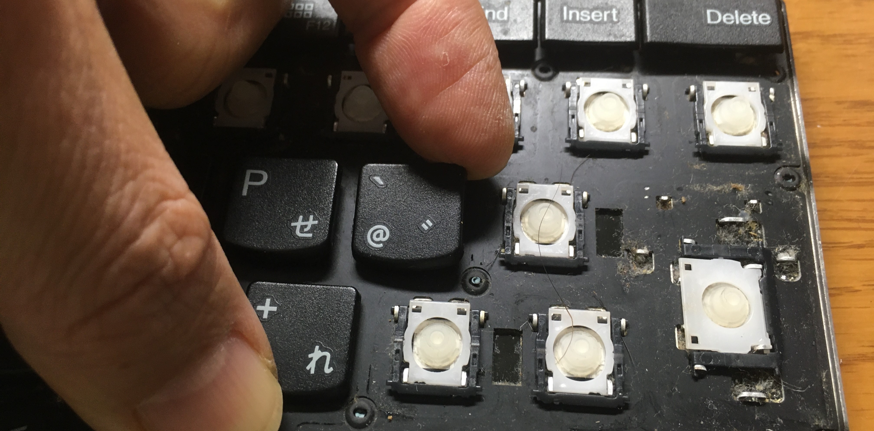
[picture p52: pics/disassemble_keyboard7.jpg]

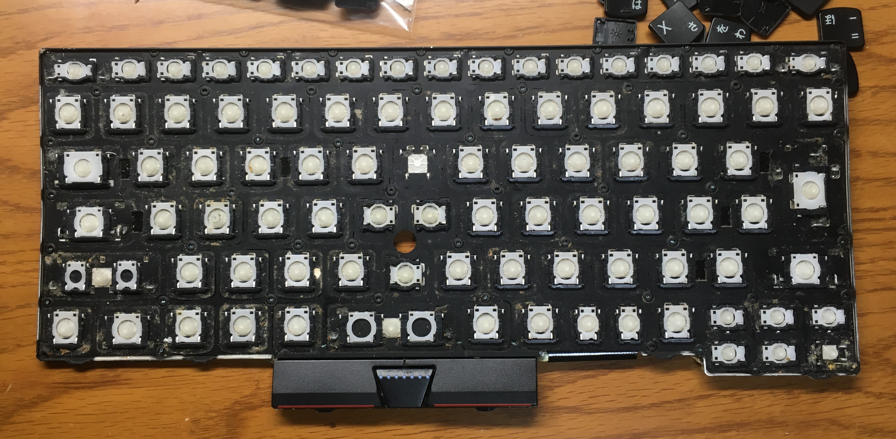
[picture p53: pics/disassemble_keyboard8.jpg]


(3) Remove all pantographs.
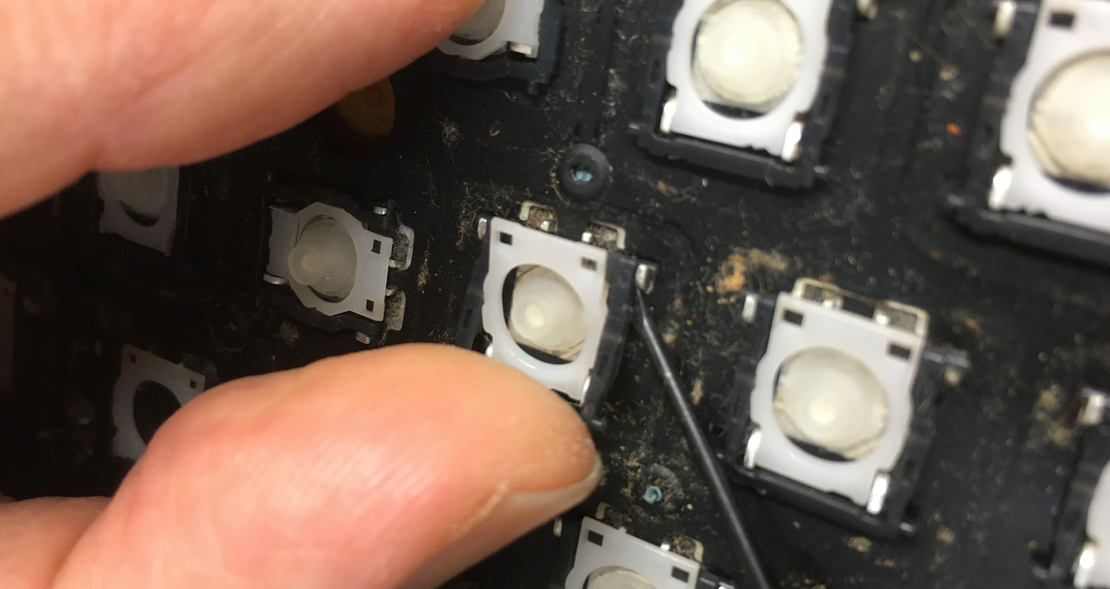
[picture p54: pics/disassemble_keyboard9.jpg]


(4) Remove the mouse buttons. They are fixed with plastic rivets.
Note! Don't break the buttons.
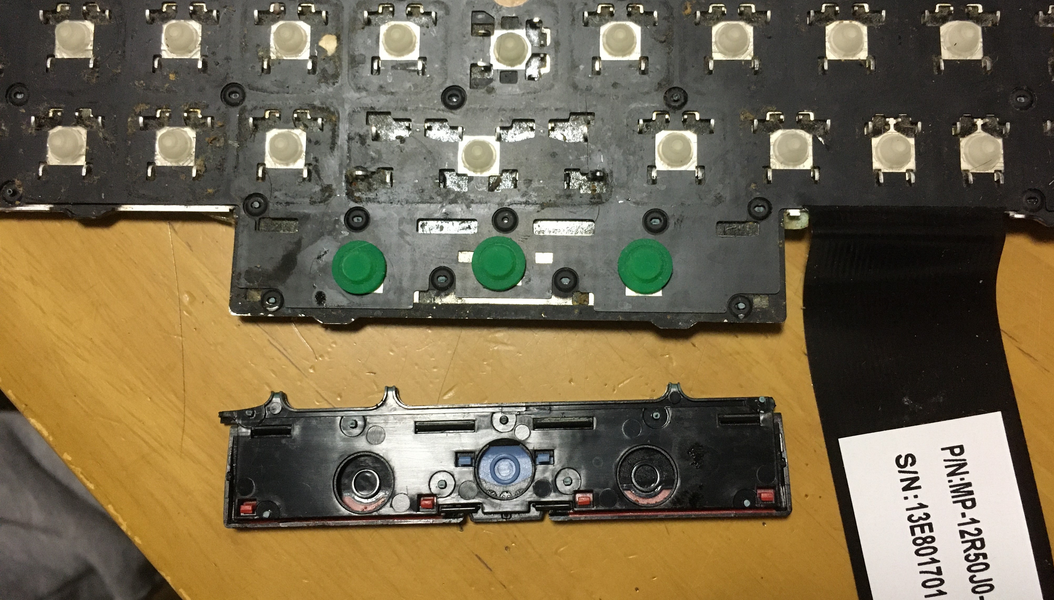
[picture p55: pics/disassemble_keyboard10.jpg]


(5) Then, you can get the FPC sheet.
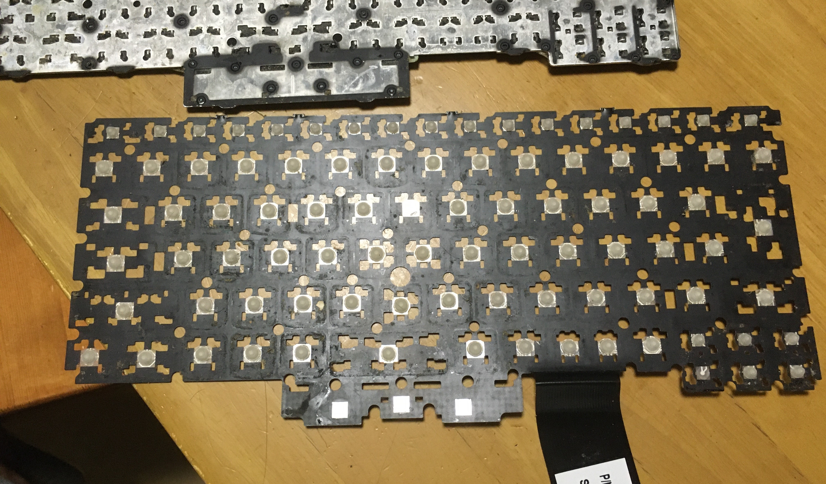
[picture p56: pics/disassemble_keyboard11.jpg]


(6) You can use the FPC after peeling off the membrane.
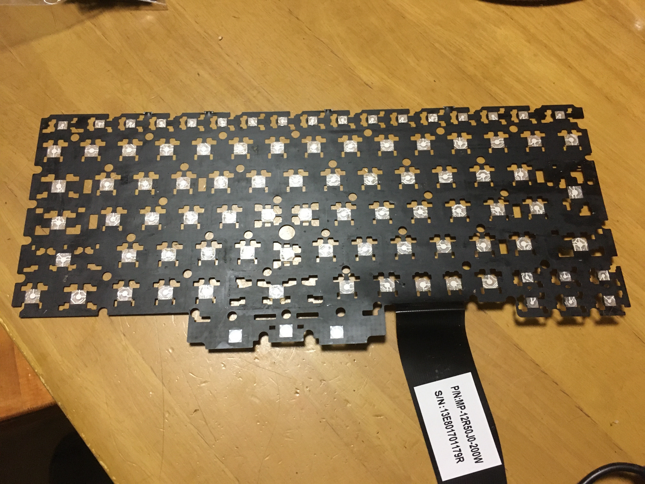
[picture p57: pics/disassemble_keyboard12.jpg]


<!-- I cut out the unnecessary part of the sheet, for avoiding unintended keyswitch reactions. But, when the cut part gets wet, it may make abnormal contact. It may be better not to cut more than necessary. -->
At least, you should cut 4 parts.
- for avoiding unintended keyswitch reactions. We need only 4 lines of connector for the mouse switches.
- for the Trackpoint module
- for the MCU place
- for the FPC connector of the Trackpoint module

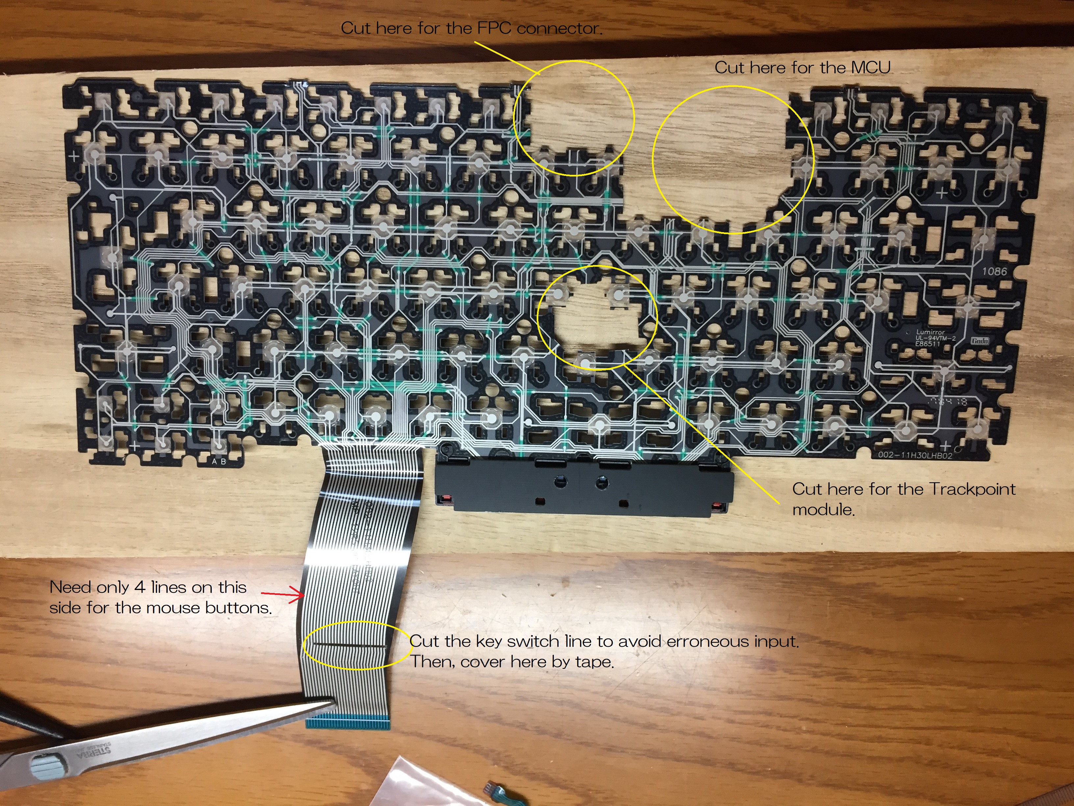
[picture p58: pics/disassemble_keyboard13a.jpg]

<!-- ![13](pics/disassemble_keyboard13.jpg) --->

This pic is the sheet of Japanese keyboard. If you will cut the sheet, investigate the necessary circuit area of the mouse switches for your keyboard.

You can see a pic how you can cut the US keyboard menbraine sheet [in this web site](https://amaya382.hatenablog.jp/entry/2015/08/14/015954).

<!-- The mouse switches need only four lines of right side.
![14](pics/disassemble_keyboard14.jpg) -->

<!--
Remove unnecessary parts.
![15](pics/assemble_keyboard01.jpg)
![16](pics/assemble_keyboard02.jpg) -->

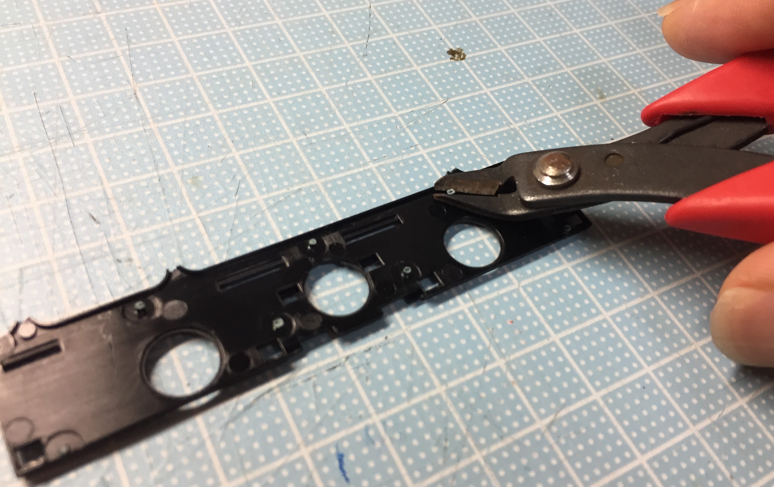
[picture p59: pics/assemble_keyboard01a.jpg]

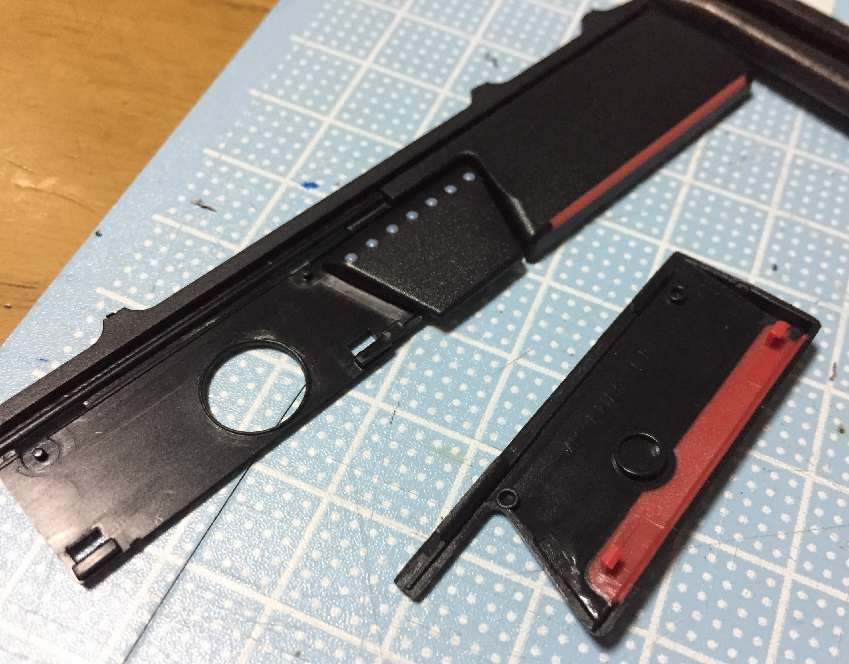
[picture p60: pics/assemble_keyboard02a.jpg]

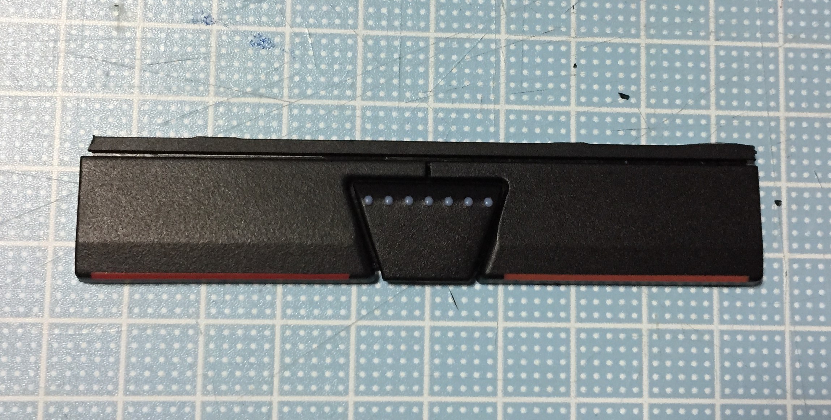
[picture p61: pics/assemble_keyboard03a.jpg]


<!-- ![17](pics/assemble_keyboard03.jpg) -->
<!-- ![18](pics/assemble_keyboard04.jpg) -->

Put the rubber parts and some double-sided tapes on the membrane sheet.

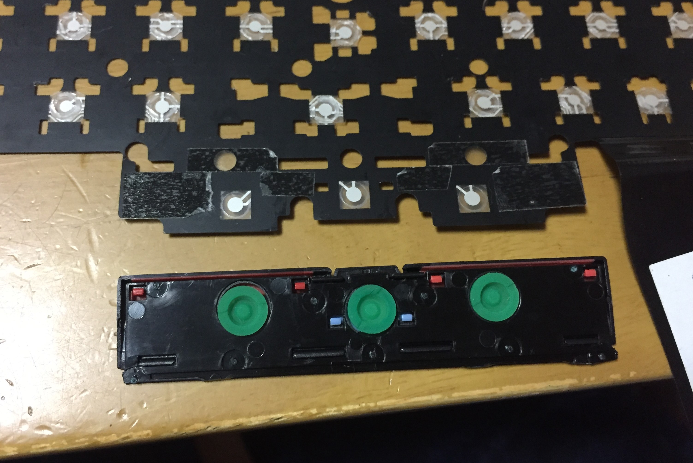
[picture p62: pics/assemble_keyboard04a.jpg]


Put the sheet in the correct position on it.

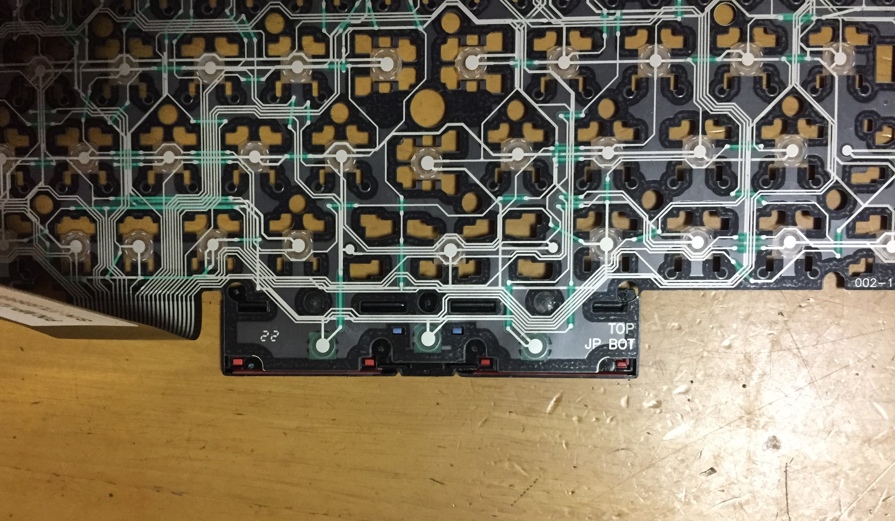
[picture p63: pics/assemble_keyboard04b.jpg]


Put the backplate in the correct position on it with some double-sided tape. Sorry, I forgot to make two holes on the plate. Make two holes like the pic on the plate before putting, for avoiding touching the button's parts.

<!-- ![19](pics/assemble_keyboard05.jpg) -->
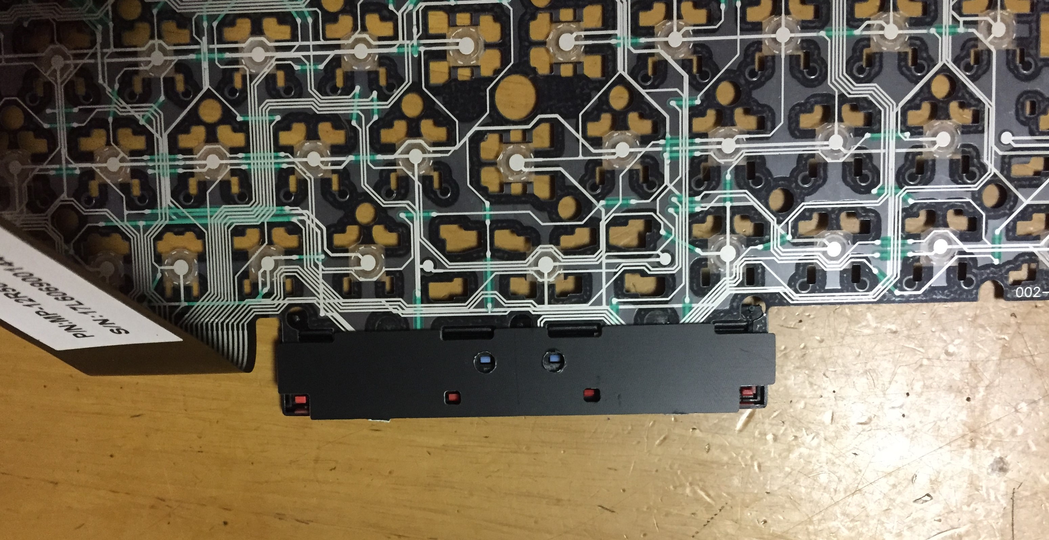
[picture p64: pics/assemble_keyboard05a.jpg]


Tape the mouse switch plate on the case for increasing height.

<!-- ![20](pics/assemble_keyboard06.jpg)  -->
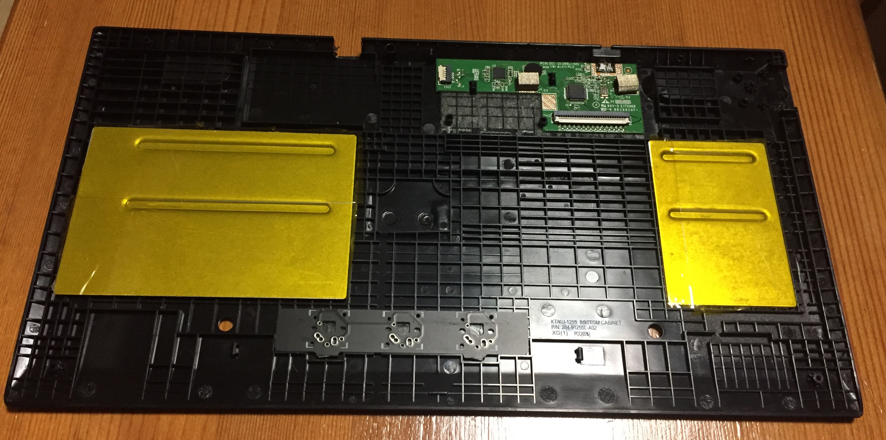
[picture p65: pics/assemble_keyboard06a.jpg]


Tape the switches and sheet on it.

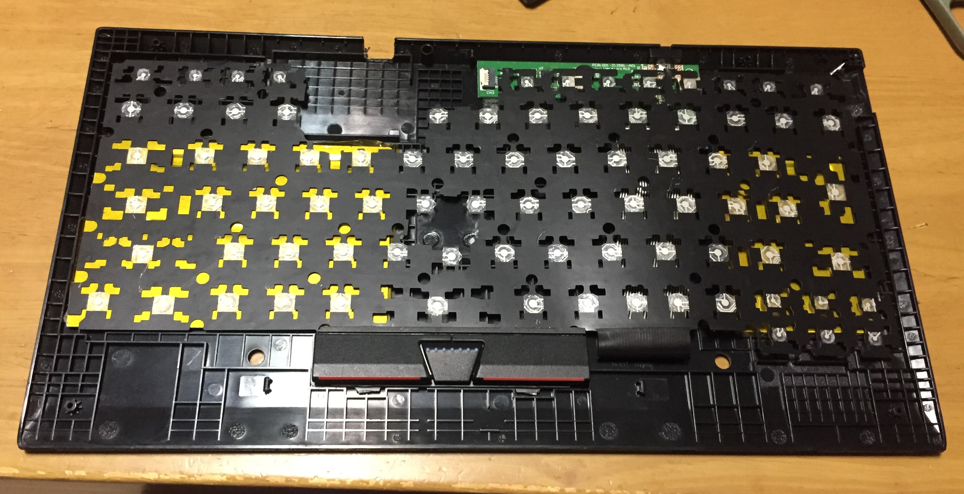
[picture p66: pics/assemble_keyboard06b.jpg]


## 6. When you don't use the original mouse button switches

Solder the 4 pins FFC connector on the backside.
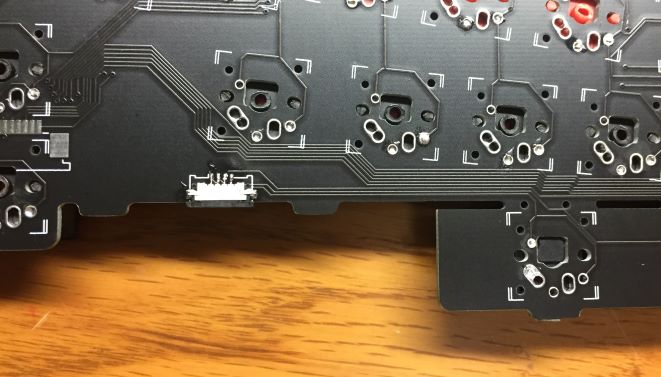
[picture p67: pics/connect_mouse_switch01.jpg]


Connect to the right side of the large connector of the casing by the 4 pins FFC.
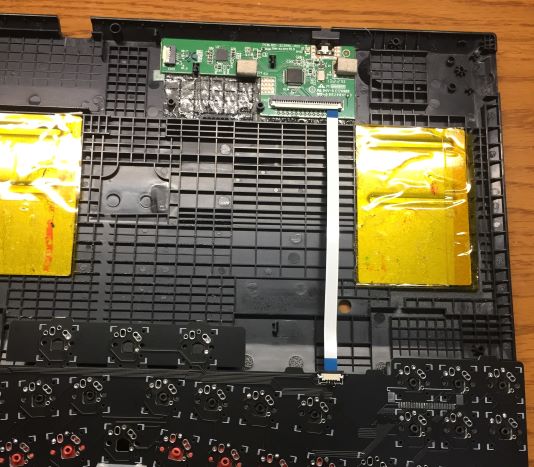
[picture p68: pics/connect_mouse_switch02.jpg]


Fold the extra length of the FFC off the board.
And install 3 switches for the mouse buttons. For the mouse switches, direct connections are enough instead of the diodes.

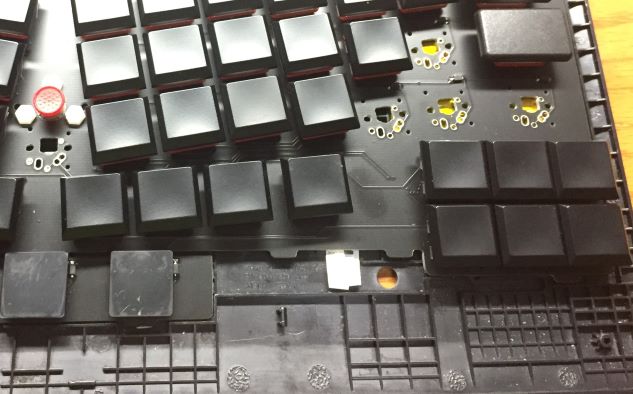
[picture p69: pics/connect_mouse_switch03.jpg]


## 7. Install the keyboard in the case

Install the Trackpoint module with the bolts and nuts. And cut the extra bolts.


Cut out the USB plug part of the case.
Put insulating tapes on the metal plates, if you put the metal plates.


Then you can install the keyboard and cover.
Don' forget to connect the FFCs.

<!-- ![40](pics/assemble_keyboard20.jpg) -->


The PCB should be under the mouse switch plate.



## 8. Install the software

Refer [QMK](https://docs.qmk.fm) Firmware.

My QMK example [here](qmk_firmware).
- 3 Layers: Base, FNC, NUM
- This arrangement is usable even if there is no top line key caps
- The default keymap is for English keyboard. 
  The jis keymap is for Japanese keyboaard

About Itsybitsy 32u4,
- Double click the rset button for resetting

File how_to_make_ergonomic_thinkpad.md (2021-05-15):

## Parts list

- MCU: Adafruit ItsyBitsy 32u4 x 1 pcs
- Key switches: Kaih [X Switch](https://www.kailhswitch.com/mechanical-keyboard-switches/low-profile-key-switches/thin-notebook-mechanical-key-switch.html) x 68 pcs

    (Actually, I don't like the touch feeling of X-Switch. but, it seems the only key switch we can get for laptop. I'm looking forward to selling the Cherry [MX Ultra Low Profile switch](https://www.cherrymx.de/en/blog/cherry-mx-ultra-low-profile.html). )
- Keycaps: [by Aliexpress](https://www.aliexpress.com/item/32987116768.html) x 68 pcs

    (I dyed black by SDN dye.)

- SMD Diodes: 1N4148W or similar x 68 pcs
- Tactile switch: C&K [KMR211NG LFS](https://www.digikey.com/en/products/detail/c-k/KMR211NG-LFS/2176494) or compatible x 1 pcs
- FFC connector: 22pos, 1.0mm pitch, Würth Elektronik [686122148922](https://www.digikey.jp/product-detail/en/w%C3%BCrth-elektronik/686122148922/732-6026-1-ND/5047585) or compatible x 1 pcs

    (The height have to be less than 2.5mm.)
- USB micro B plug: GCT [USB3150-30-130-A](https://www.digikey.jp/product-detail/en/USB3150-30-130-A/2073-USB3150-30-130-ACT-ND/9859720) or compatible x 1 pcs
- FFC cable: [22pos, 1.0mm pitch, 100mm length](https://www.digikey.jp/product-detail/en/686722100001/732-5138-ND/4573366) or Compatible x 1 pcs

- Trackpoint module: disassemble from T470s keyboard
- Trackpoint cap: by [Saoto-Tech](https://www.etsy.com/shop/SaotoTech) (optional) x 1pcs

## Assemble the board

## Remove the original keyboard from the ThinkPad T470s

## Install the keyboard in the ThinkPad

## Install the software

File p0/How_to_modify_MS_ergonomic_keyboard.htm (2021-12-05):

How to install the Trackpoint module in the MS ergonomic keyboard.

2021-12-05 preliminary

キーボードとマウス 自動的に生成された説明

1. Parts list

1.1. Keyboard:

Microsoft Ergonomic Keyboard LXM-00018 or LXN-00018

1.2. Trackpoint module:

Replacement keyboard for ThinkPad X100 X100E X120 X120E

(I bought this keyboard at Aliexpress.)

ノートパソコンのキーボード米国英語版ibmレノボthinkpad X100 X100E x120 X120E

Or you can try another module with help of these web sites.

https://deskthority.net/wiki/TrackPoint_Hardware

https://github.com/joric/jorne/wiki/Trackpoint

1.3. MCU:

Arduino Beetle or Compatible

電子機器の部品 低い精度で自動的に生成された説明

1.4. PCBs:

I made three PCBs.

PCB for the MCU

PCB for the 8 pos FFC connector

PCB for the 4 pos FFC connector

1.5. Screw:

M2 x 0.25(fine pitch) x 4 mm x 2 pcs

1.6. FFC connectors:

1.0 mm pitch 8 pos x 1pcs (e.g.)Molex Easy-On 200529

1.0 mm pitch 4 pos x 1pcs (e.g.) Würth Elektronik 686104183522

1.7. Miscellaneous electronics components:

4.7 k ohm resistor x2

100 k ohm resistor x1

2.2 u F capacitor x1

Some wires

1.8. USB connection

USB A female connector

USB HUB board

回路 が含まれている画像 自動的に生成された説明 Moechando USBハブコントローラ基板 FE1.1S搭載

1.9. TrackPoint cap (optional)

https://www.etsy.com/listing/707617816/low-profile-softrim-type-3d-printed-caps

2. Circuit diagram

No. 1 & 2 are

Dummy.

3 - 6

ダイアグラム 中程度の精度で自動的に生成された説明

Actual circuit



3. Disassemble and Modify the keyboard of ThinkPad X100

3.1. Remove the Trackpoint module from the keyboard by removing the four screws



3.2. Remove all keycaps

Basically, you can remove the caps from upper or left hand side excluding "G", "B", "↑", and "↓".
タイプライターのキーボード 自動的に生成された説明

3.3. Remove the plastic frame

キーボードの上に置かれている 低い精度で自動的に生成された説明

You should cut here (the yellow circles).



3.4. Remove all Pantographs

Using a small screwdriver.

https://youtu.be/yqRD0r0fuKo

3.5. Cut the unnecessary large part of the steel plate

Be careful not to damage the FPC sheet.



3.6. Cut the unnecessary part of the FPC sheet.

And remove the membrane cups.

テーブル が含まれている画像 自動的に生成された説明
We need this area of the FPC, because the GND line is running around, if this is the US keyboard of X100.

3.7. Treat the edges of the steel plate to avoid damaging the FPC sheet

レゴ, 座る, テーブル, リモコン が含まれている画像 自動的に生成された説明

3.8. Round the remaining FPC



3.9. Bend the switch plate for a good feeling

ナイフを持っている手 低い精度で自動的に生成された説明

3.10. Cut the FPC terminal and take out pins 3 to 6



4. Disassemble and Modify the MS ergonomic keyboard



4.1. Remove 5 screws under the rubber feet.

白黒の写真 中程度の精度で自動的に生成された説明

4.2. Remove the palm rest

It is a bit hard. I'd destroyed several claws.

 

 

4.3. Remove some keycaps over the screws

キーボードとマウス 自動的に生成された説明



4.4. Remove all screws over the top

Then, you can open the keyboard.

4.5. Cut the urethane mat for putting the Trackpoint switches

It should be a bit larger than the switch plate.



4.6. Make some holes

     

4.7. Remove this portion

For making space for putting the MCU.

 

5. Install the components

5.1. Install the Trackpoint switch on the palm rest



5.2. Fix the palm rest and the Trackpoint module on the keyboard upper case

屋内, 座る, 荷物, スーツケース が含まれている画像 自動的に生成された説明

5.3. Connect the MCU circuit



5.4. Insert the USB Hub between the MS keyboard PCB and output

on the keyboard lower case

ダイアグラム 自動的に生成された説明

5.5. Connect the MCU to USB hub



6. Install the software in the MCU

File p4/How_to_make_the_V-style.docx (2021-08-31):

How to make the V-style layout

(1) Decide the comfortable home position


(2) Check the pinky easily moving area


(3) Check the thumb movable area


(4) Add all finger movement areas


(5) Tentatively decide the switches position


(6) Put the switches


(7) Adjust position for ease of use


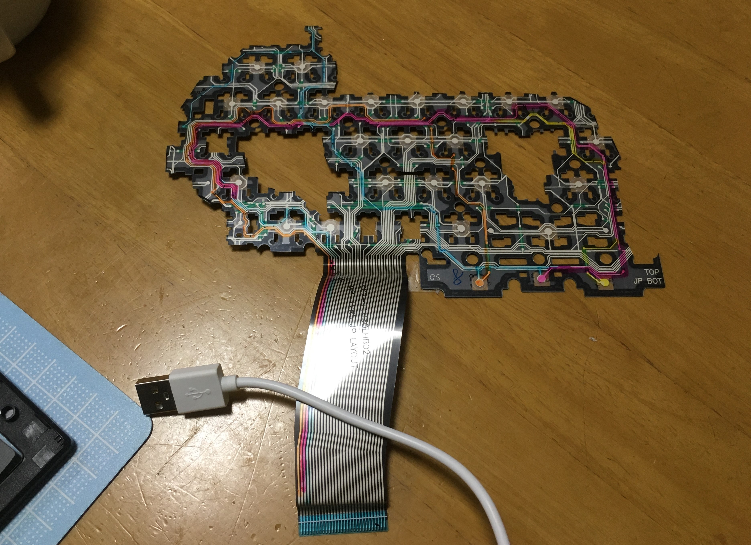
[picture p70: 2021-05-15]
pics/disassemble_keyboard13.jpg

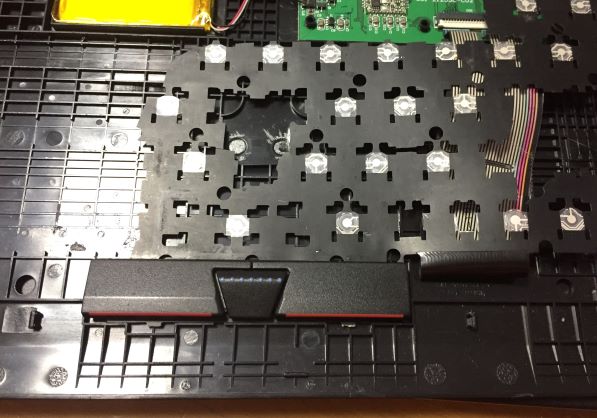
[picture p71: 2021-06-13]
pics/assemble_keyboard06.jpg

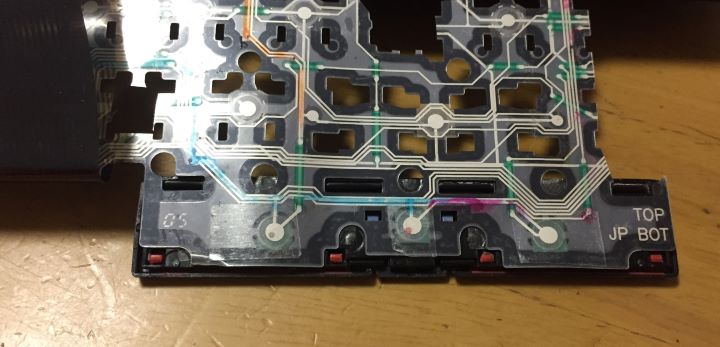
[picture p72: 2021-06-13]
pics/assemble_keyboard04.jpg

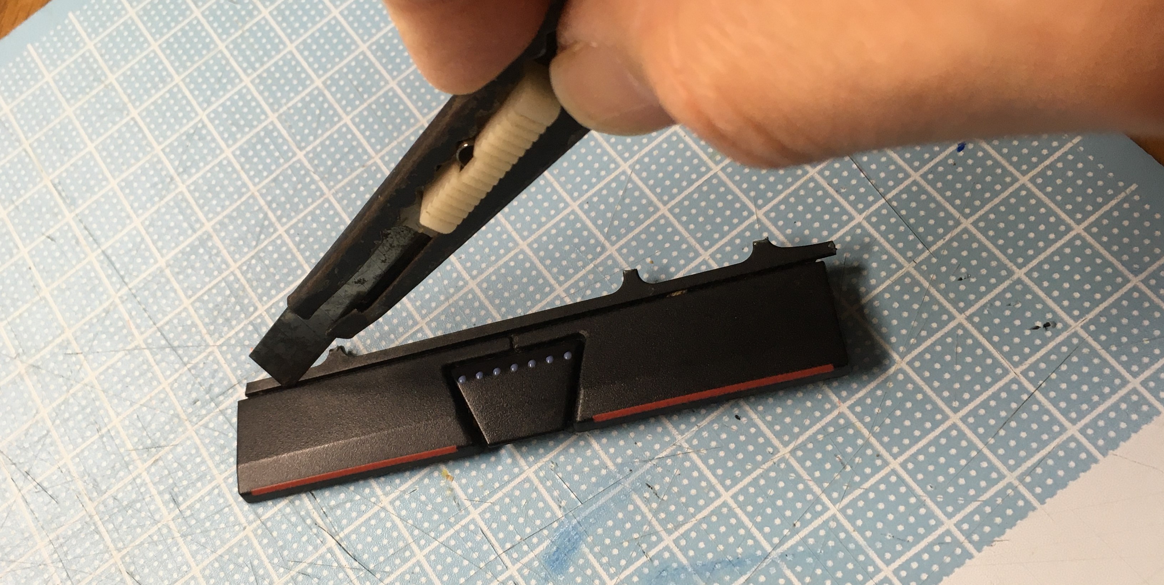
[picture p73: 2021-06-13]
pics/assemble_keyboard01.jpg

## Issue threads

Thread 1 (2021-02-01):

schematic and footprint

dennisleexyz, 2021-02-01:
I saw you uploaded PDFs from KiCad. Will you be uploading the source files too?

You inspired me to work on a very similar project, so I am interested to use the Kailh X switch PCB footprint and see how the trackpoint connection is made. Thanks :)

saoto28, 2021-02-01:
Though I'm not confident with my cad data, I put my KiCad data on the repository for just reference.
Maybe there is some missing data. Please point out.

dennisleexyz, 2021-02-03:
I was able to export footprints from your PCB for external use.

I looked up the switch footprint and found issue by you (shikamiya/kicad-footprint-kailh-pg1425-x-switch#2). Is it fixed in your PCB?

saoto28, 2021-02-03:
Yes, it is.
The attachment is a part of my first PCB drawing.
A and B are the pin points of Kailh x switch. But, the x switch has two steel points bottom besides of the pin points. And the steel points are connecting to pin A in the switch. The steel points may touch the C port of the PCB. Then the A pin and B pin may always connected.
So, I removed the D connection on my second PCB. When you use MX or ALPS switch, you have to connect the D.
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
And, the hole sizes for Kailh switches were not correct. I will correct them.

saoto28, 2021-03-06:
I've uploaded a footprint that was corrected about the pad's size for the choc and x-switch.
https://github.com/saoto28/pineapple60/tree/main/KiCad/kailh-pg1425-x-switch.pretty

saoto28, 2021-05-13:
I found a bad point in the footprint. The corner curvature of the square hole for the X-switch was too big. Some X-switch is not inserted smoothly. I'll make the curvature small.

saoto28, 2021-05-25:
The CAD drawing was no problem. The curvature is 0.25 radius. It looks small enough. So, it was just a manufacturing issue of JLCPCB.

Closed 2021-05-25.

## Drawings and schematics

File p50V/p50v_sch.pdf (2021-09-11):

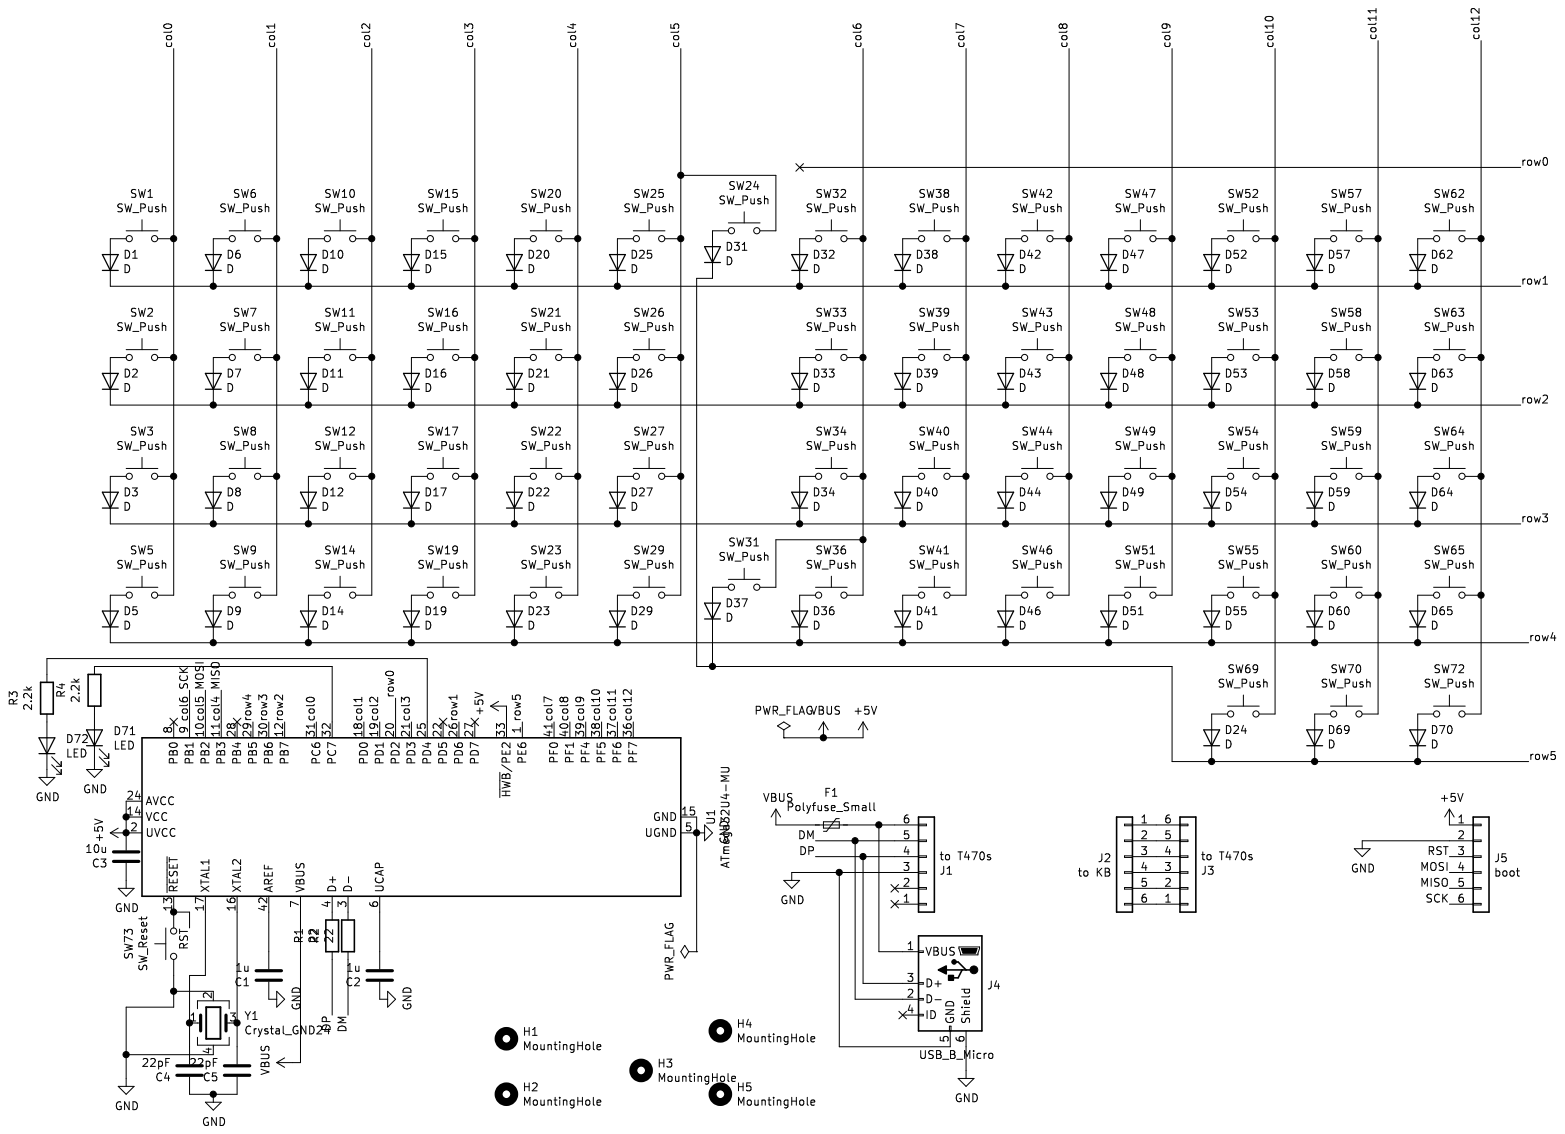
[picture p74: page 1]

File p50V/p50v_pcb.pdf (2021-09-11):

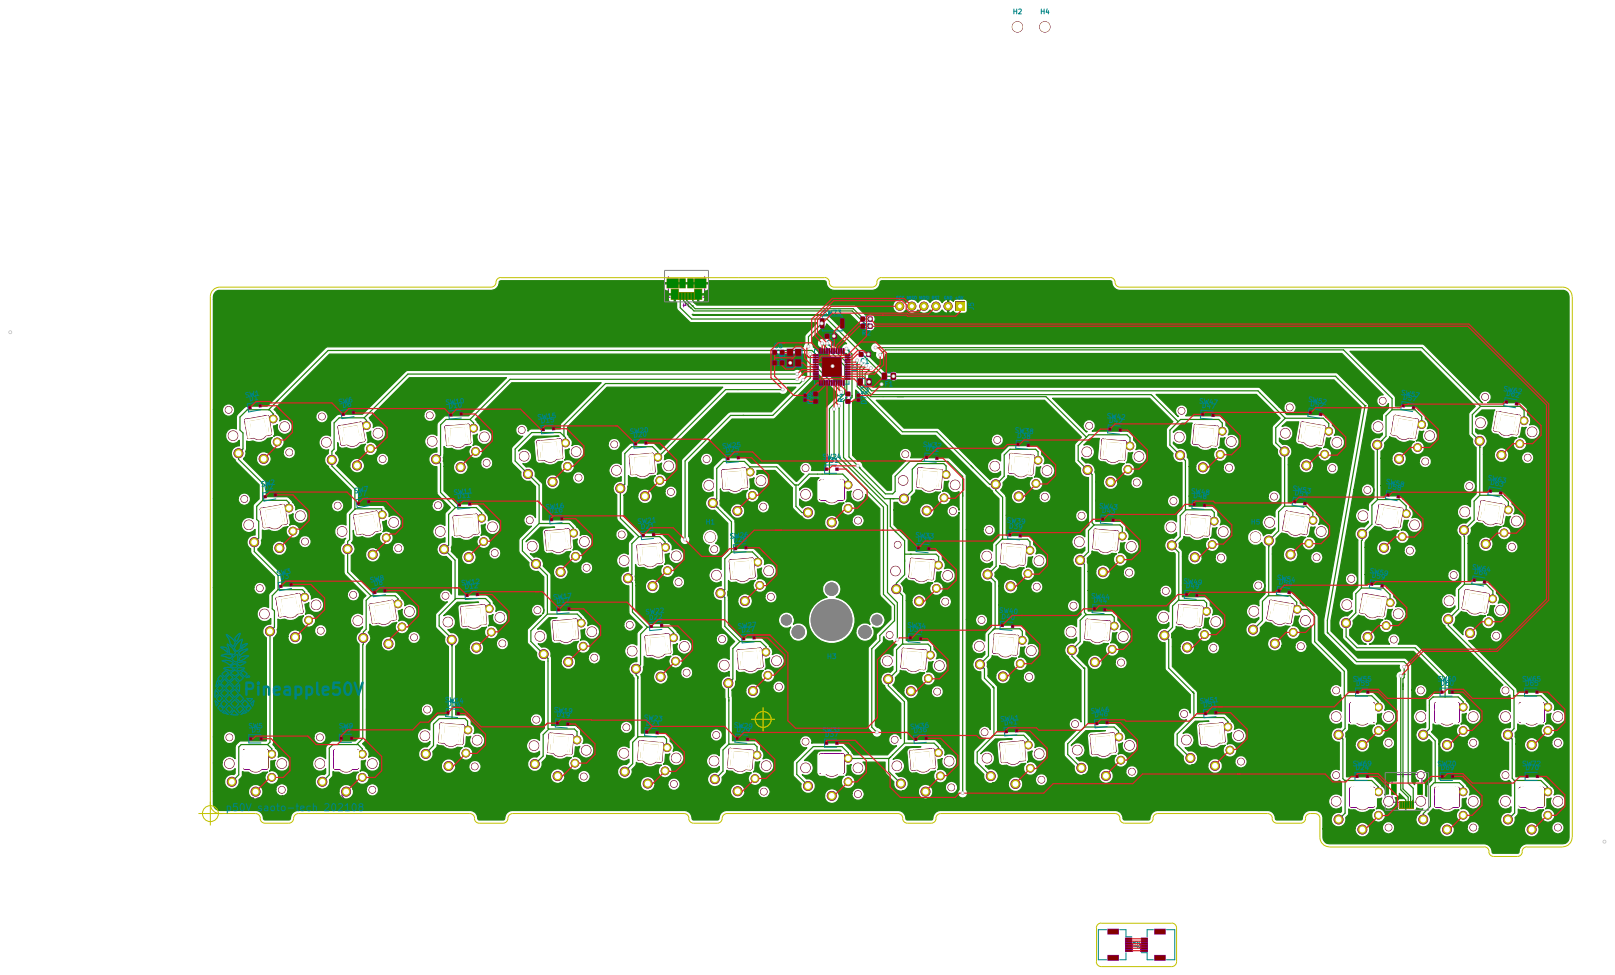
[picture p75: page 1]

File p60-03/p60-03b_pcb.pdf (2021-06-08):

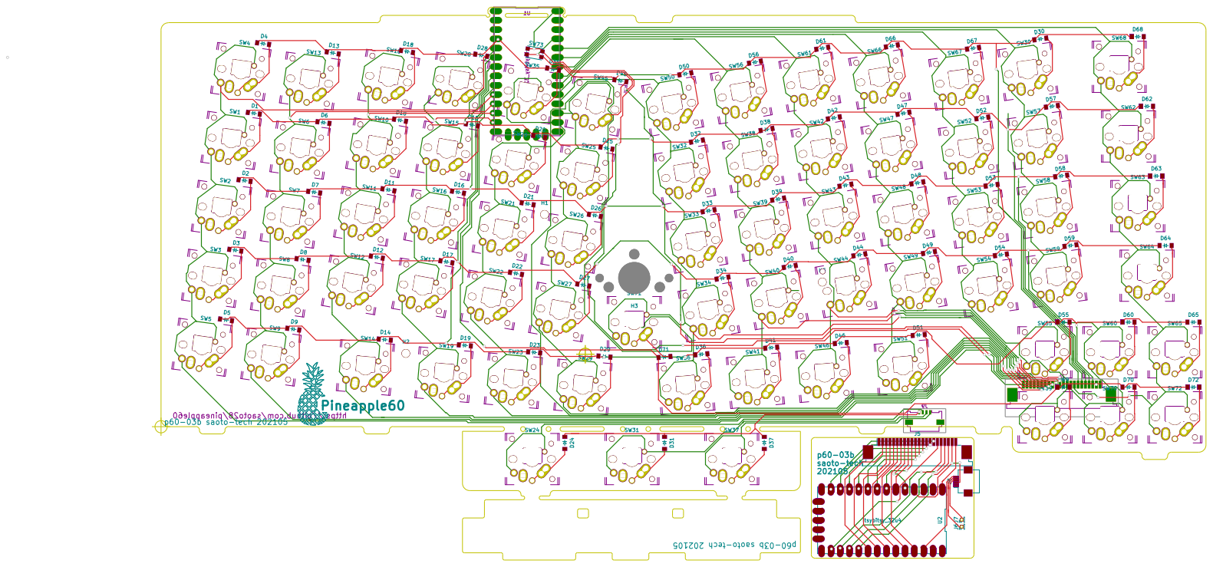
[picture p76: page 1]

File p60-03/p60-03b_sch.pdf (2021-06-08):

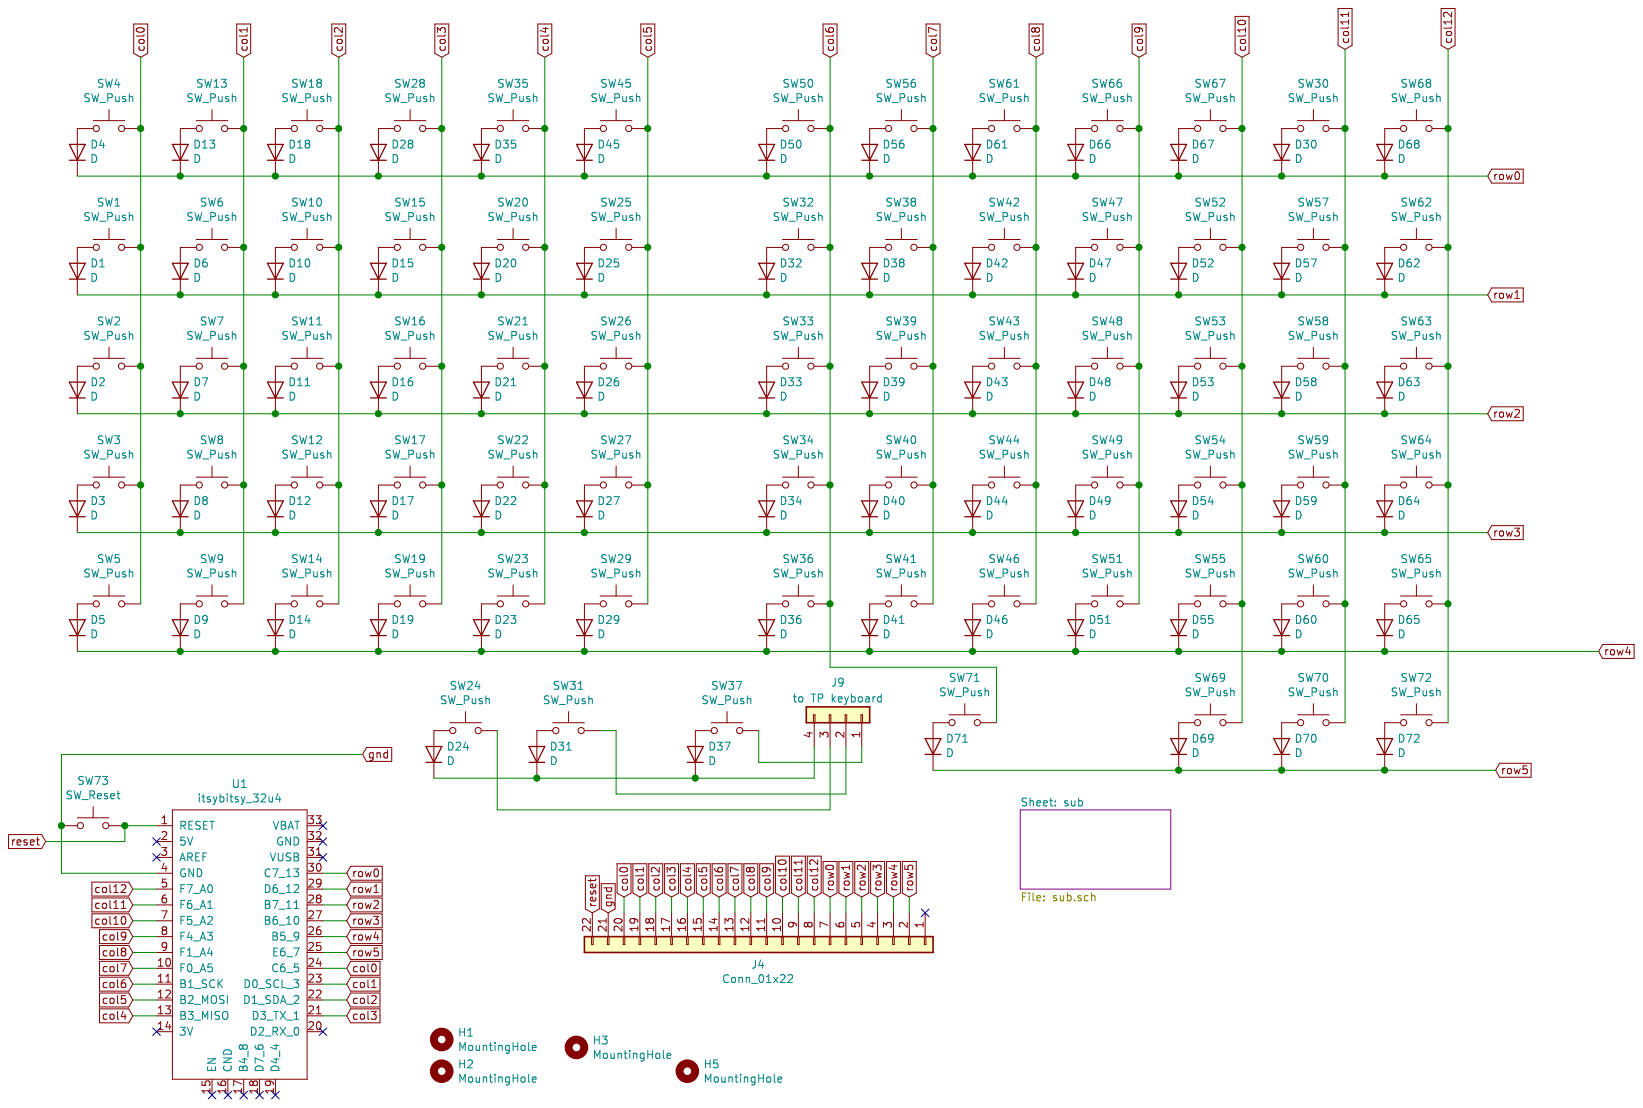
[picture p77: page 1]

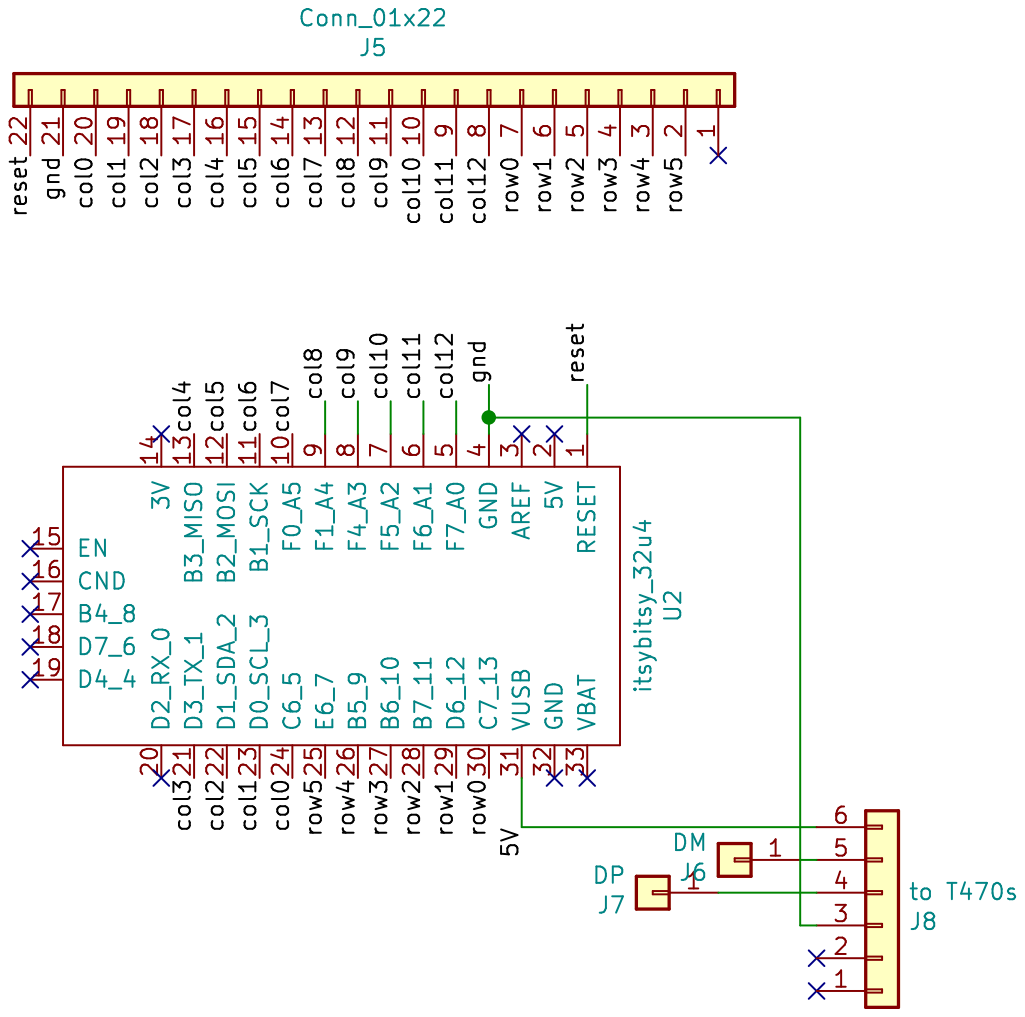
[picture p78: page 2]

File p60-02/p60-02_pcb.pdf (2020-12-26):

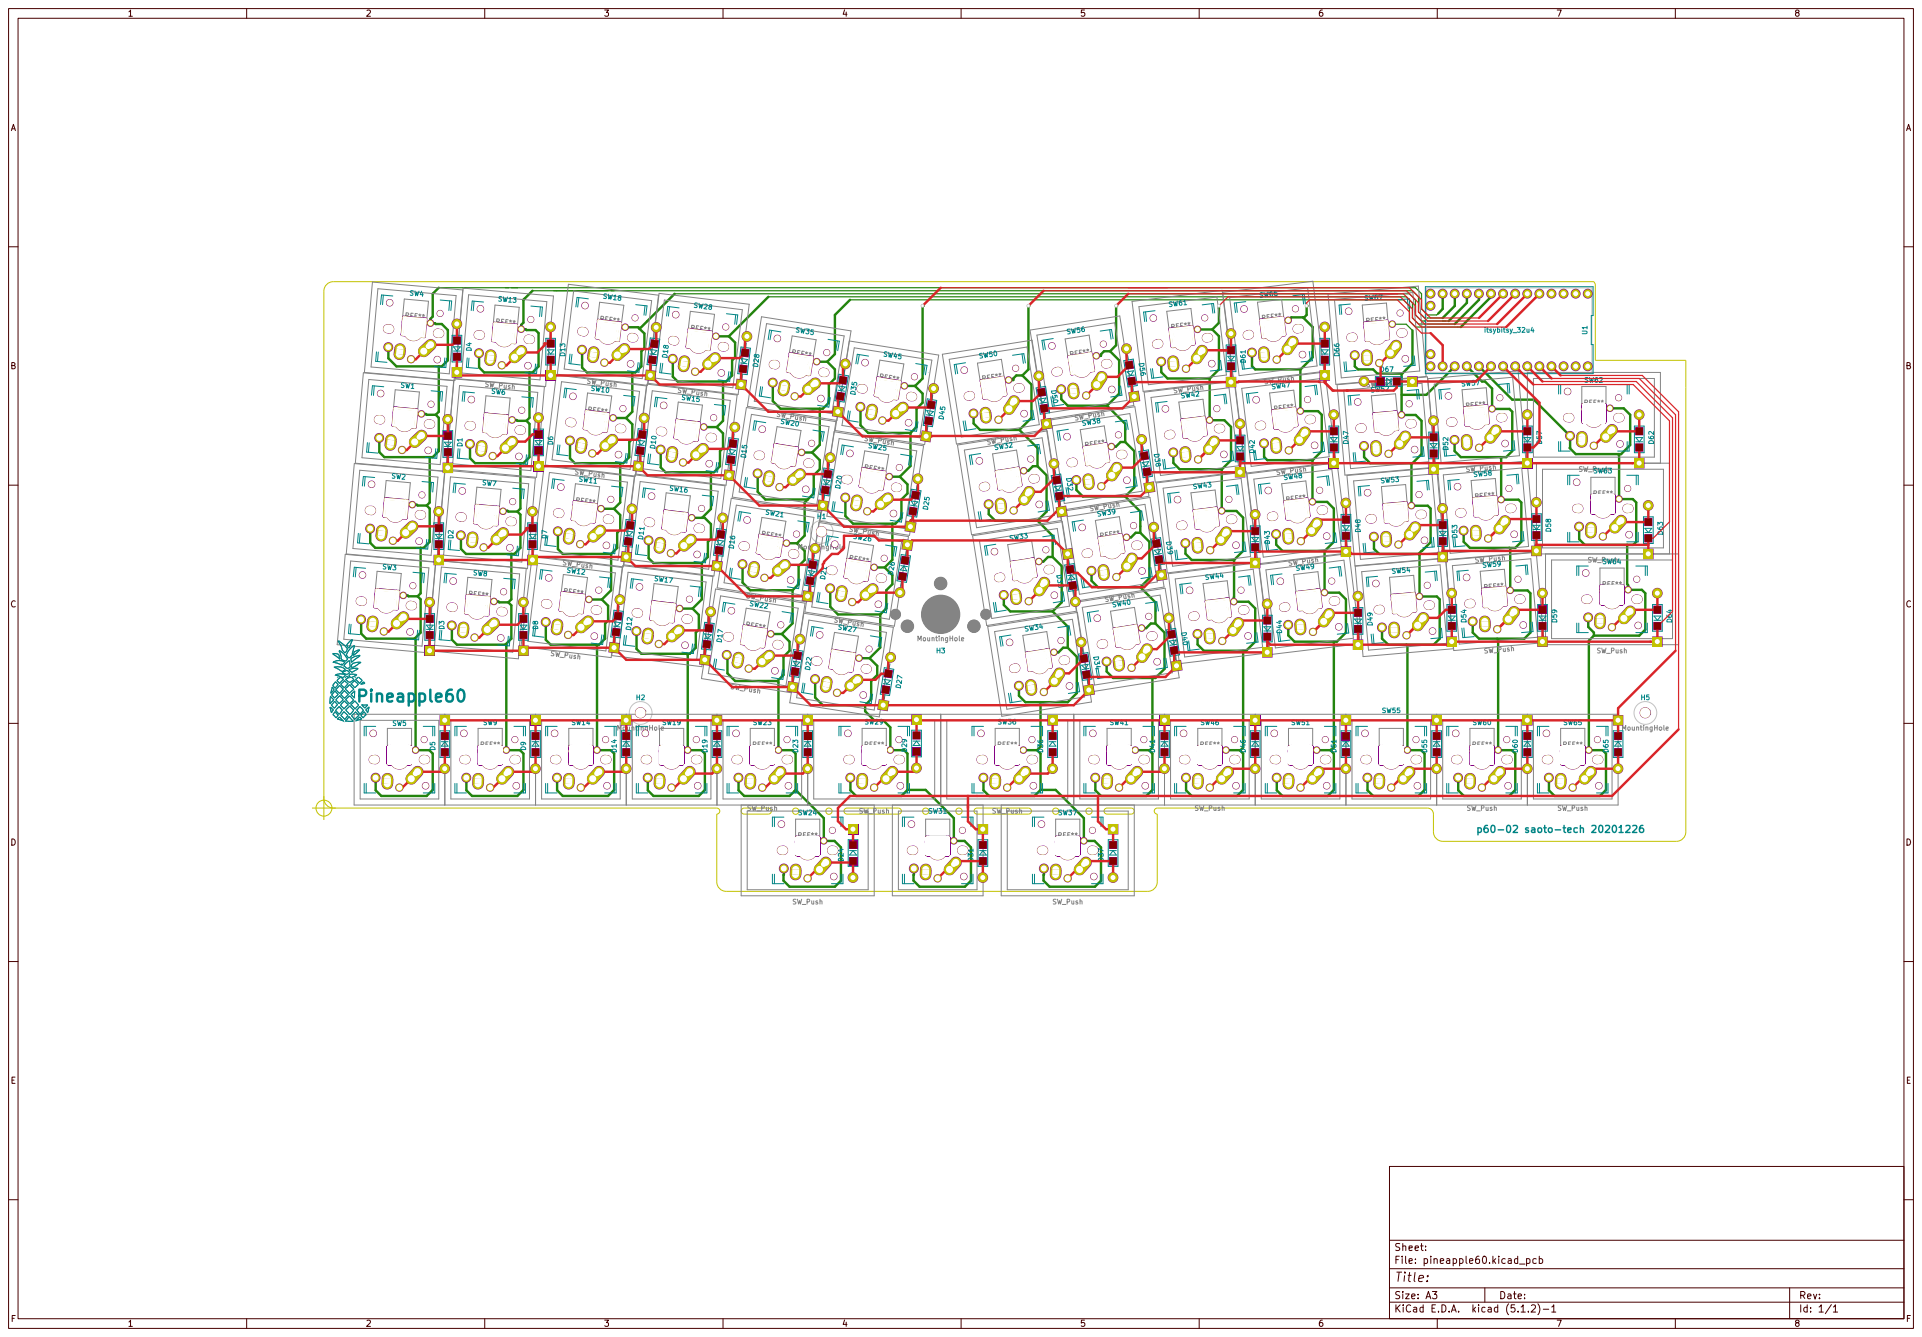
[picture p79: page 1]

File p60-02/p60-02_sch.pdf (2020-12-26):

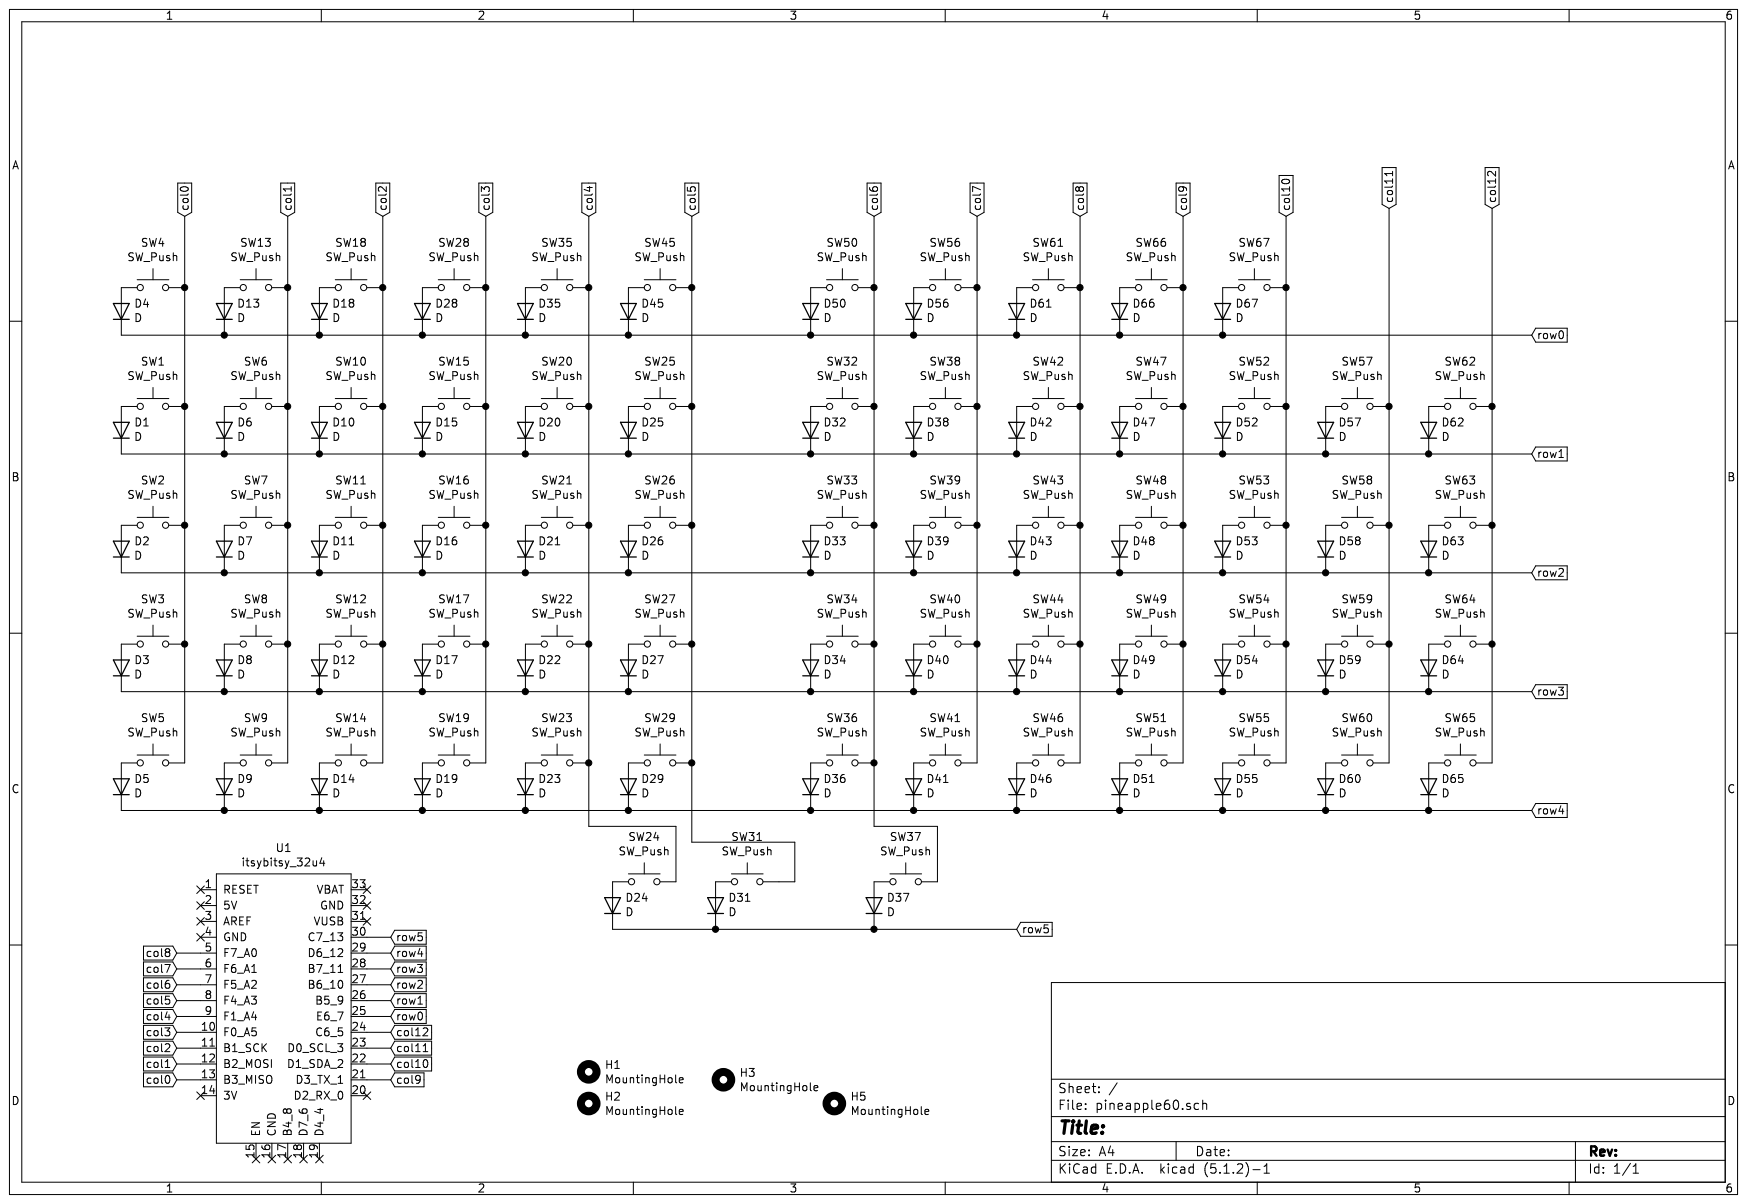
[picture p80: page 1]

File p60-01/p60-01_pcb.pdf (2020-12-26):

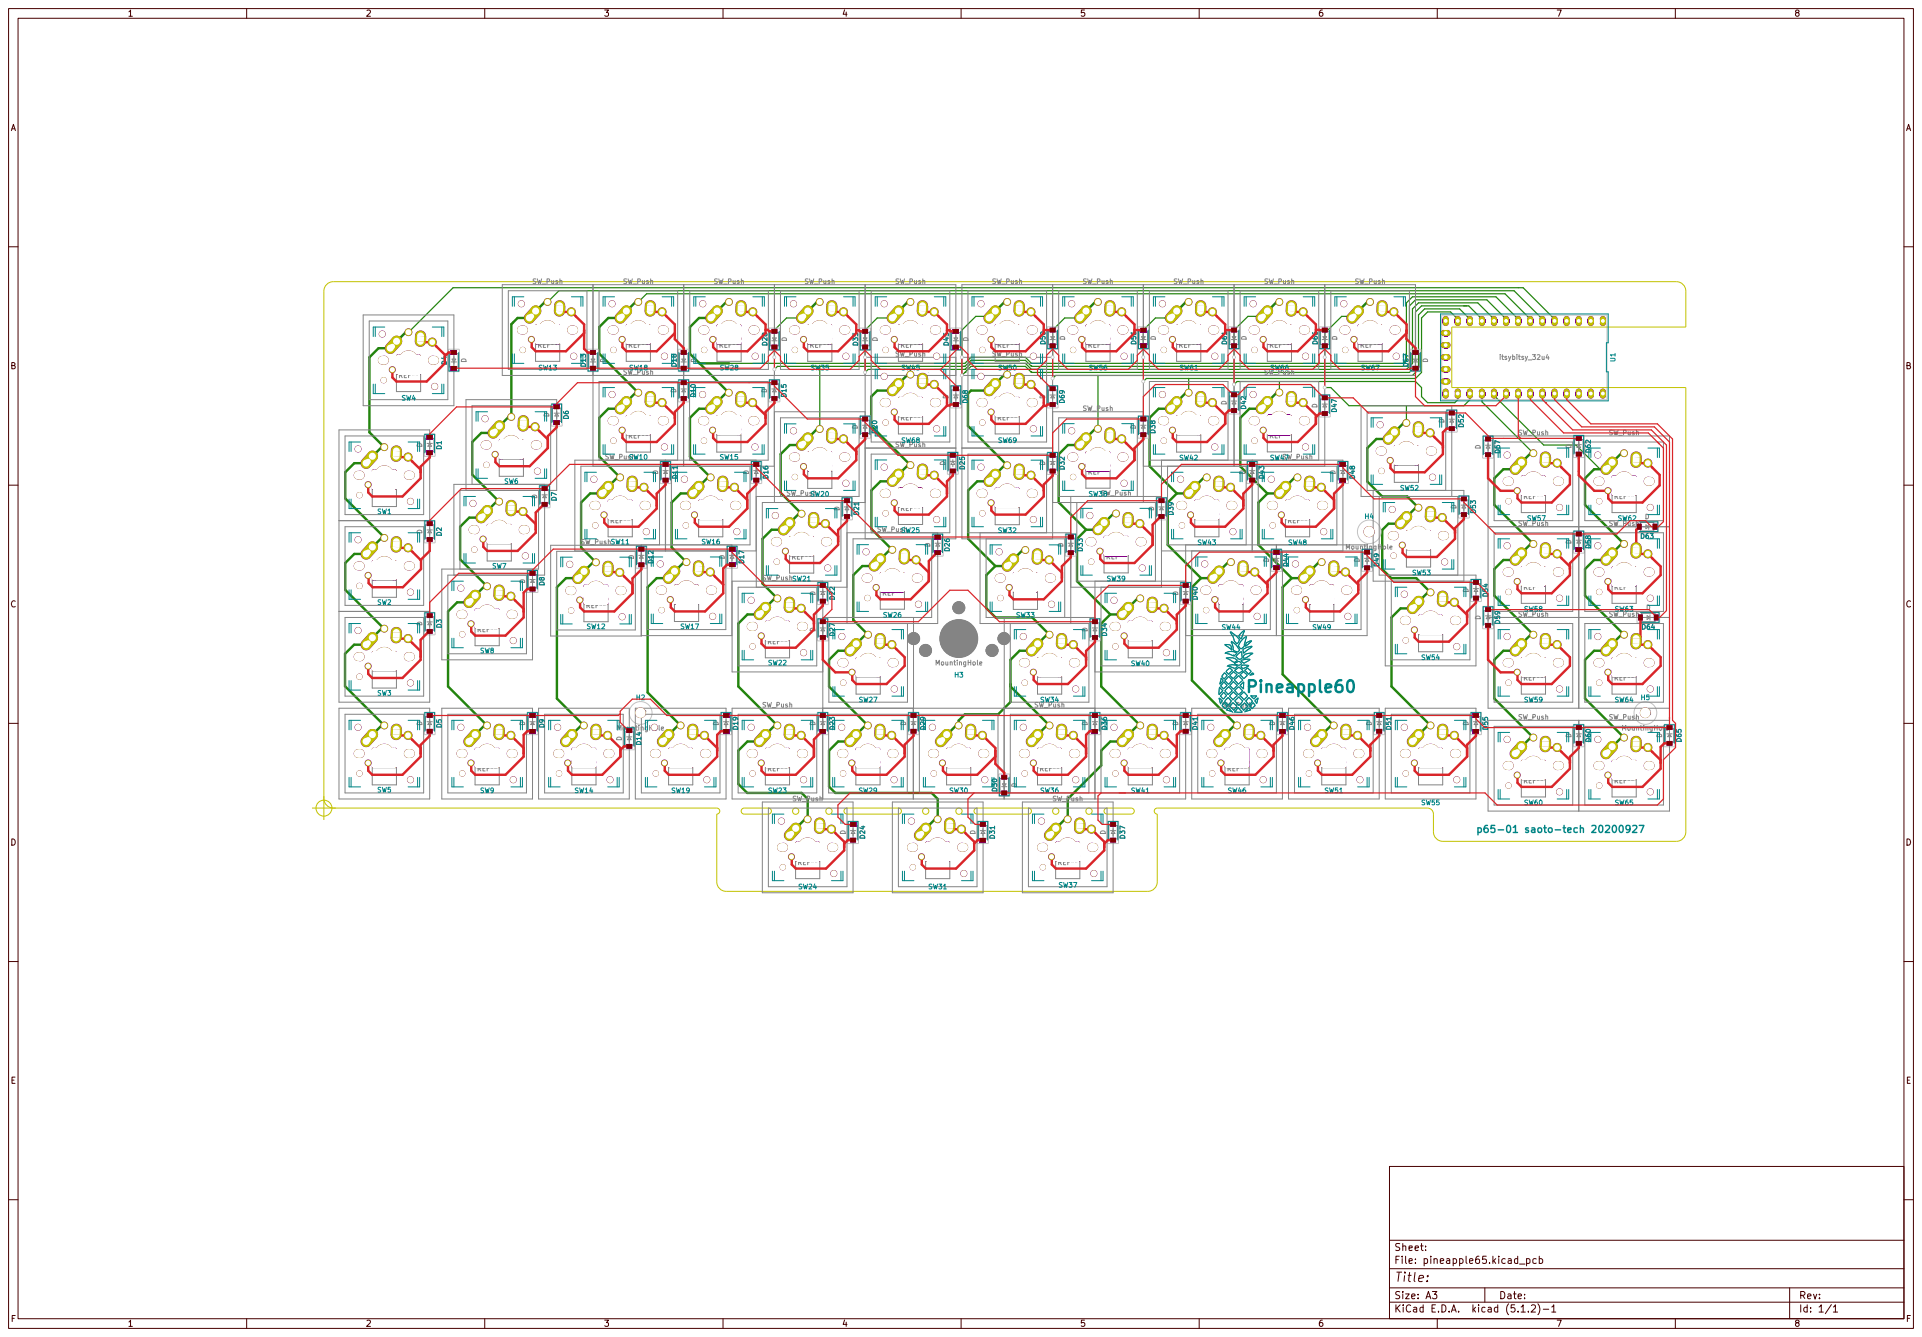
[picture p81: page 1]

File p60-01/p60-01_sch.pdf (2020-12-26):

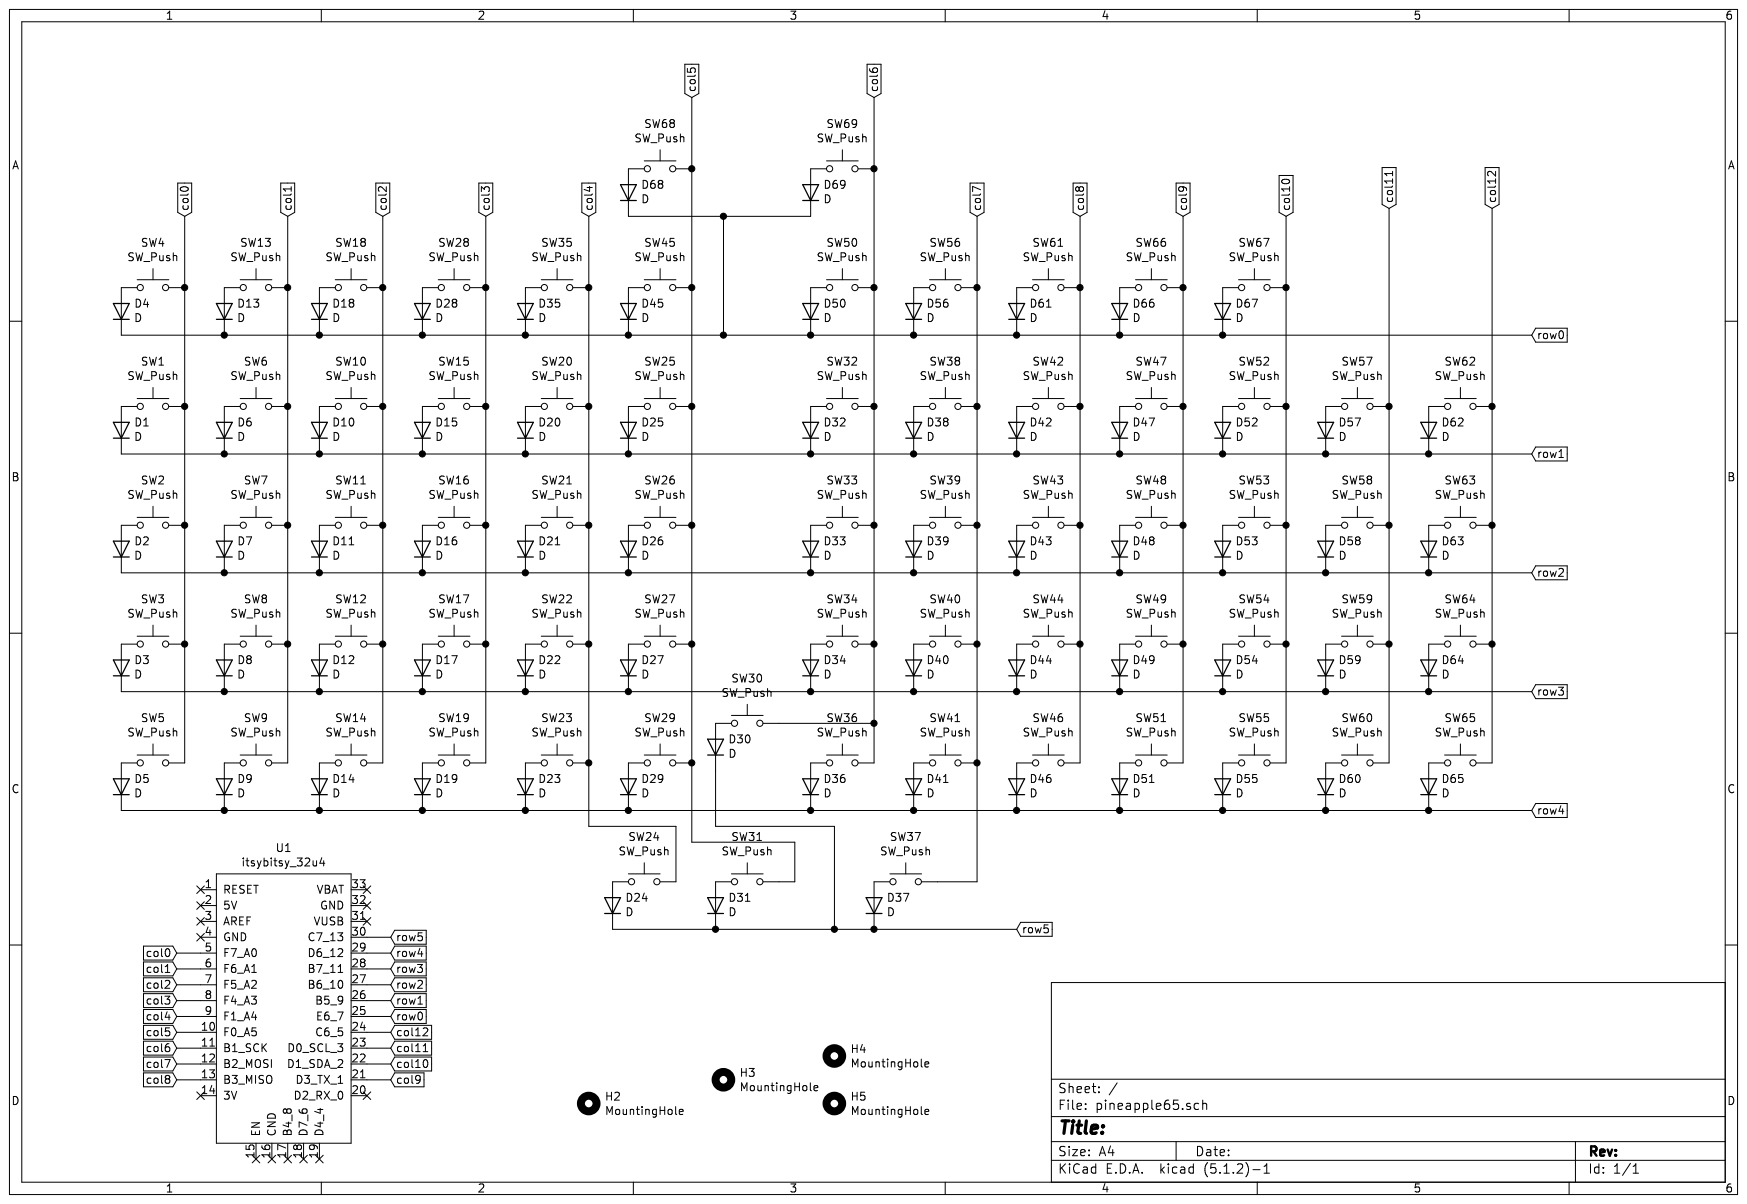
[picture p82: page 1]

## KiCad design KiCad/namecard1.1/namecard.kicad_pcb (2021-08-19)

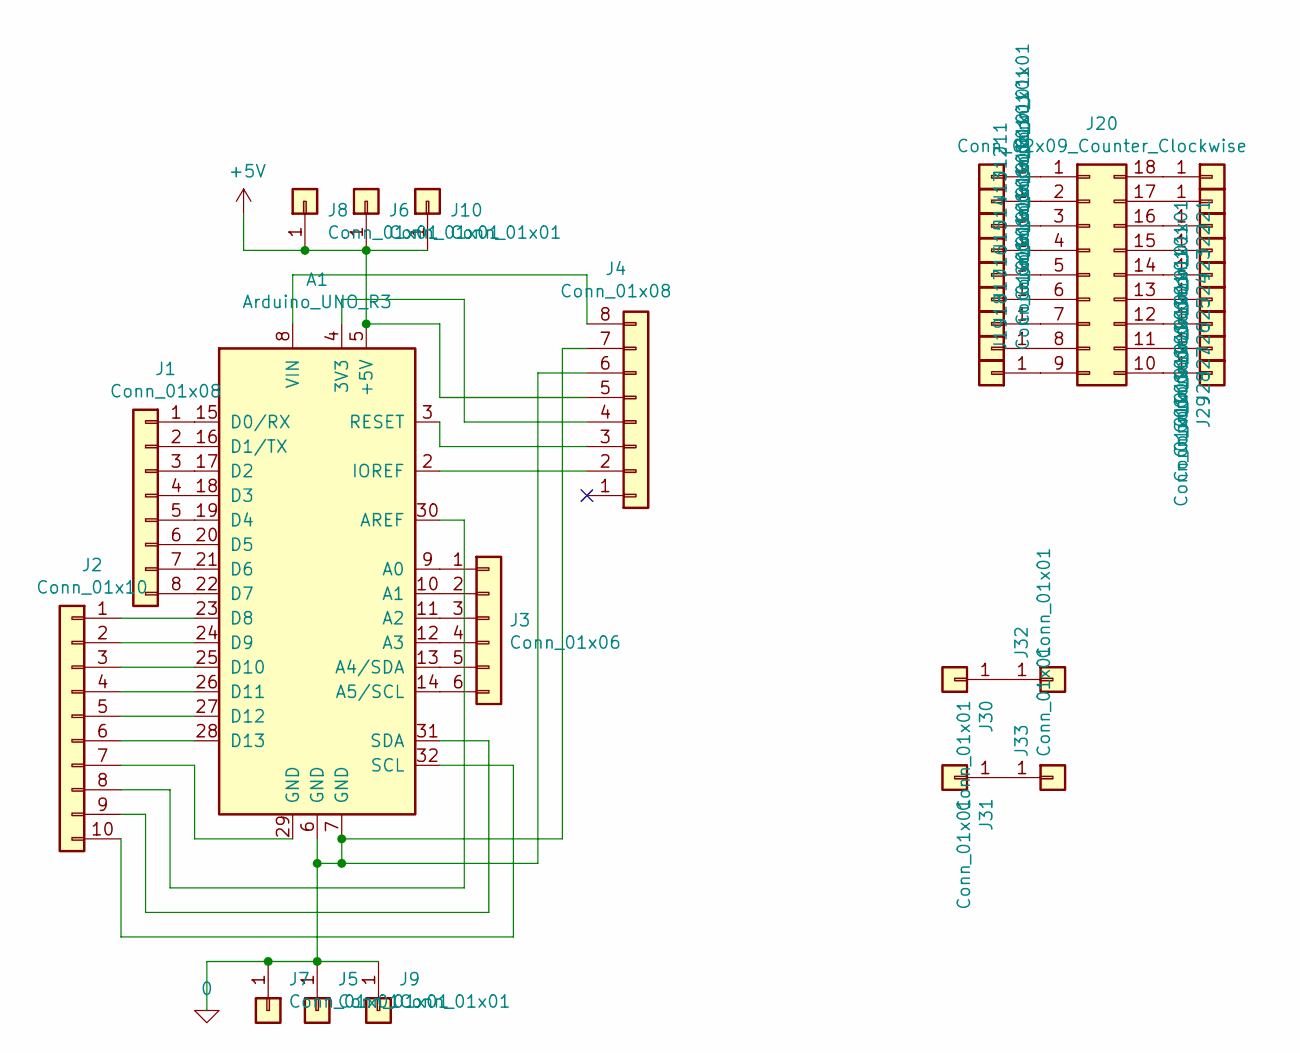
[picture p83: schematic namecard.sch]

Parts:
A1: Arduino_UNO_R3
J1, J4: Conn_01x08; PinHeader_1x08_P2.54mm_Vertical
J2: Conn_01x10; PinHeader_1x10_P2.54mm_Vertical
J3: Conn_01x06; PinHeader_1x06_P2.54mm_Vertical
J5, J6, J7, J8, J9, J10, J30, J31, J32, J33: Conn_01x01; SolderWirePad_1x01_Drill1.0mm_1.7
J11, J12, J13, J14, J15, J16, J17, J18, J19, J21, J22, J23, J24, J25, J26, J27, J28, J29: Conn_01x01; SolderWirePad_1x01_Drill1.0mm_1.7_no-mark
J20: Conn_02x09_Counter_Clockwise; SOP-18_7x12.5mm_P1.27mm_mod

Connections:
unnamed: A1.1 (NC), A1.29 (GND), J2.7
unnamed: A1.2 (IOREF), J4.2
unnamed: A1.3 (RESET), J4.3
unnamed: A1.4 (3V3), J4.4
unnamed: A1.8 (VIN), J4.8
unnamed: A1.9 (A0), J3.1
unnamed: A1.10 (A1), J3.2
unnamed: A1.11 (A2), J3.3
unnamed: A1.12 (A3), J3.4
unnamed: A1.13 (A4/SDA), J3.5
unnamed: A1.14 (A5/SCL), J3.6
unnamed: A1.15 (D0/RX), J1.1
unnamed: A1.16 (D1/TX), J1.2
unnamed: A1.17 (D2), J1.3
unnamed: A1.18 (D3), J1.4
unnamed: A1.19 (D4), J1.5
unnamed: A1.20 (D5), J1.6
unnamed: A1.21 (D6), J1.7
unnamed: A1.22 (D7), J1.8
unnamed: A1.23 (D8), J2.1
unnamed: A1.24 (D9), J2.2
unnamed: A1.25 (D10), J2.3
unnamed: A1.26 (D11), J2.4
unnamed: A1.27 (D12), J2.5
unnamed: A1.28 (D13), J2.6
unnamed: A1.30 (AREF), J2.8
unnamed: A1.31 (SDA), J2.9
unnamed: A1.32 (SCL), J2.10
unnamed: J11.1, J20.1
unnamed: J12.1, J20.2
unnamed: J13.1, J20.3
unnamed: J14.1, J20.4
unnamed: J15.1, J20.5
unnamed: J16.1, J20.6
unnamed: J17.1, J20.7
unnamed: J18.1, J20.8
unnamed: J19.1, J20.9
unnamed: J20.10, J29.1
unnamed: J20.11, J28.1
unnamed: J20.12, J27.1
unnamed: J20.13, J26.1
unnamed: J20.14, J25.1
unnamed: J20.15, J24.1
unnamed: J20.16, J23.1
unnamed: J20.17, J22.1
unnamed: J20.18, J21.1
unnamed: J30.1, J32.1
unnamed: J31.1, J33.1

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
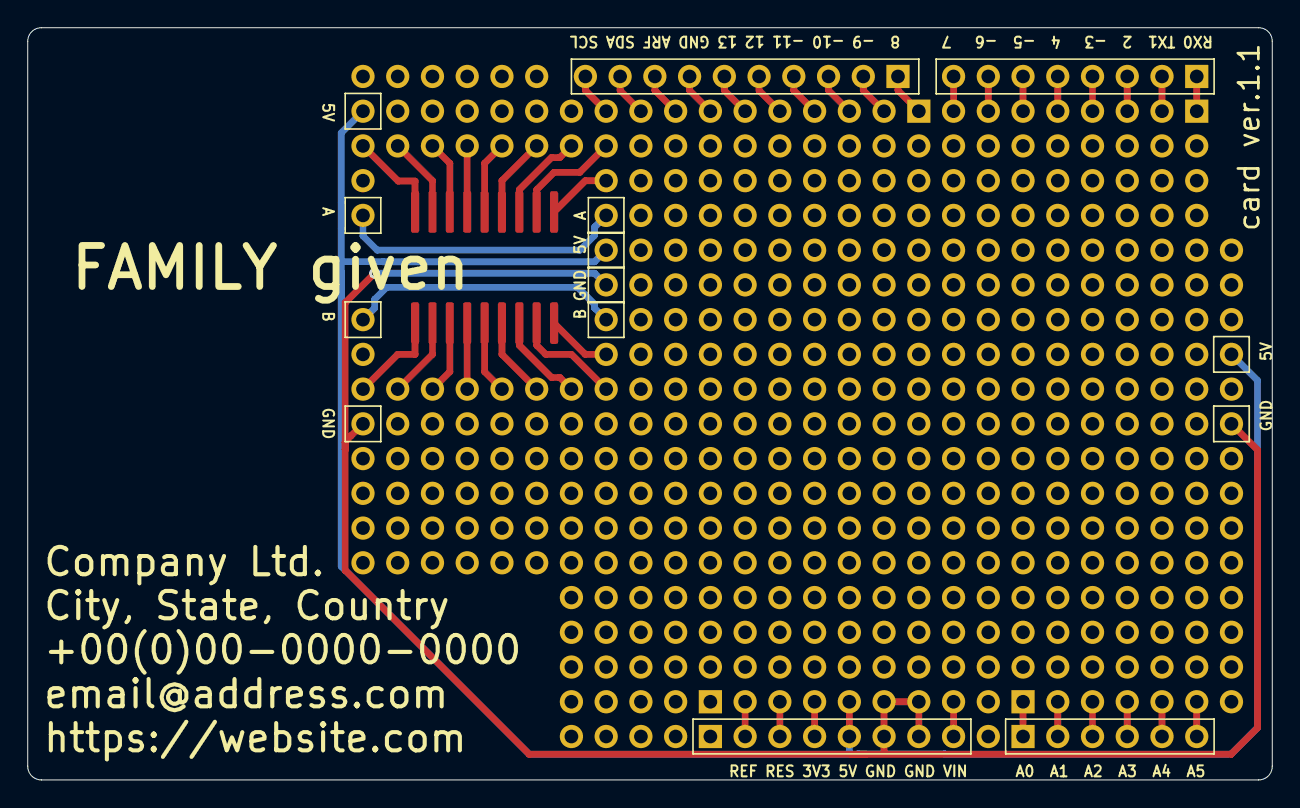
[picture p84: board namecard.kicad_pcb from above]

Board: 2 copper layers, 91.0 x 55.0 mm, 34 parts (1 on the bottom side), 50 nets.

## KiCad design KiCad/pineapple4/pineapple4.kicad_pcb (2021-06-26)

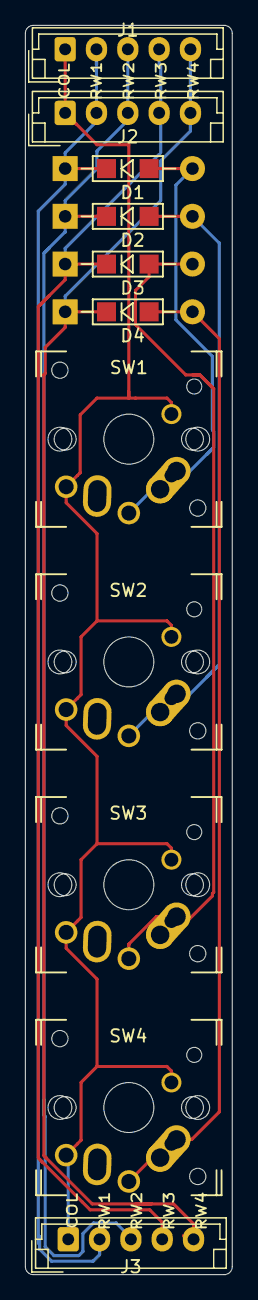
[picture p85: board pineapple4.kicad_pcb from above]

Board: 2 copper layers, 16.5 x 99.7 mm, 11 parts (0 on the bottom side), 9 nets.

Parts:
D1, D2, D3, D4: D; Diode_TH_SOD123
J1, J2, J3: Conn_01x05; JST_EH_B5B-EH-A_1x05_P2.50mm_Vertical
SW1, SW2, SW3, SW4: SW_Push; MX-ALPS-Choc-X-straight-oneside

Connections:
unnamed: D1.1, J1.2, J2.2, J3.2
unnamed: D1.2, SW1.2
unnamed: D2.1, J1.3, J2.3, J3.3
unnamed: D2.2, SW2.2
unnamed: D3.1, J1.4, J2.4, J3.4
unnamed: D3.2, SW3.2
unnamed: D4.1, J1.5, J2.5, J3.5
unnamed: D4.2, SW4.2
unnamed: J1.1, J2.1, J3.1, SW1.1, SW2.1, SW3.1, SW4.1

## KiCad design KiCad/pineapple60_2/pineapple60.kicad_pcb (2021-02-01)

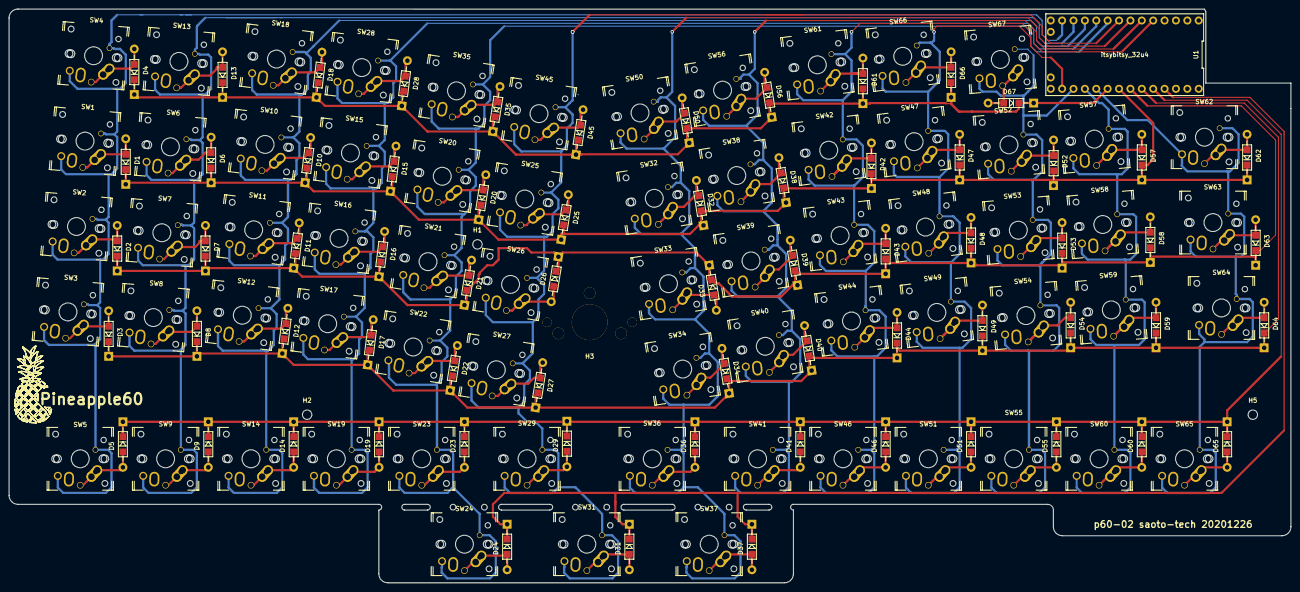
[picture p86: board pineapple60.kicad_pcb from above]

Board: 2 copper layers, 286.0 x 128.0 mm, 137 parts (0 on the bottom side), 85 nets.

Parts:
D1, D2, D3, D4, D5, D6, D7, D8, D9, D10, D11, D12, D13, D14, D15, D16, D17, D18, D19, D20, D21, D22, D23, D24, D25, D26, D27, D28, D29, D31, D32, D33, D34, D35, D36, D37, D38, D39, D40, D41, D42, D43, D44, D45, D46, D47, D48, D49, D50, D51, D52, D53, D54, D55, D56, D57, D58, D59, D60, D61, D62, D63, D64, D65, D66, D67: D; Diode_TH_SOD123
H1, H2, H5: MountingHole; MountingHole_2.1mm
H3: MountingHole; Trackpoint_KT1255
SW1, SW2, SW3, SW4, SW5, SW6, SW7, SW8, SW9, SW10, SW11, SW12, SW13, SW14, SW15, SW16, SW17, SW18, SW19, SW20, SW21, SW22, SW23, SW25, SW26, SW27, SW28, SW31, SW32, SW33, SW34, SW35, SW38, SW39, SW40, SW41, SW42, SW43, SW44, SW45, SW46, SW47, SW48, SW49, SW50, SW51, SW52, SW53, SW54, SW55, SW56, SW57, SW58, SW59, SW60, SW61, SW65, SW66, SW67: SW_Push; MX-ALPS-Choc-X-straight-oneside
SW24, SW29, SW36, SW37, SW62, SW63, SW64: SW_Push; MX-ALPS-Choc-X-straight-1.5U
U1: itsybitsy_32u4; itsybitsy_32u4_open

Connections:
unnamed: D1.2, SW1.2
unnamed: D2.2, SW2.2
unnamed: D3.2, SW3.2
unnamed: D4.2, SW4.2
unnamed: D5.2, SW5.2
unnamed: D6.2, SW6.2
unnamed: D7.2, SW7.2
unnamed: D8.2, SW8.2
unnamed: D9.2, SW9.2
unnamed: D10.2, SW10.2
unnamed: D11.2, SW11.2
unnamed: D12.2, SW12.2
unnamed: D13.2, SW13.2
unnamed: D14.2, SW14.2
unnamed: D15.2, SW15.2
unnamed: D16.2, SW16.2
unnamed: D17.2, SW17.2
unnamed: D18.2, SW18.2
unnamed: D19.2, SW19.2
unnamed: D20.2, SW20.2
unnamed: D21.2, SW21.2
unnamed: D22.2, SW22.2
unnamed: D23.2, SW23.2
unnamed: D24.2, SW24.2
unnamed: D25.2, SW25.2
unnamed: D26.2, SW26.2
unnamed: D27.2, SW27.2
unnamed: D28.2, SW28.2
unnamed: D29.2, SW29.2
unnamed: D31.2, SW31.2
unnamed: D32.2, SW32.2
unnamed: D33.2, SW33.2
unnamed: D34.2, SW34.2
unnamed: D35.2, SW35.2
unnamed: D36.2, SW36.2
unnamed: D37.2, SW37.2
unnamed: D38.2, SW38.2
unnamed: D39.2, SW39.2
unnamed: D40.2, SW40.2
unnamed: D41.2, SW41.2
unnamed: D42.2, SW42.2
unnamed: D43.2, SW43.2
unnamed: D44.2, SW44.2
unnamed: D45.2, SW45.2
unnamed: D46.2, SW46.2
unnamed: D47.2, SW47.2
unnamed: D48.2, SW48.2
unnamed: D49.2, SW49.2
unnamed: D50.2, SW50.2
unnamed: D51.2, SW51.2
unnamed: D52.2, SW52.2
unnamed: D53.2, SW53.2
unnamed: D54.2, SW54.2
unnamed: D55.2, SW55.2
unnamed: D56.2, SW56.2
unnamed: D57.2, SW57.2
unnamed: D58.2, SW58.2
unnamed: D59.2, SW59.2
unnamed: D60.2, SW60.2
unnamed: D61.2, SW61.2
unnamed: D62.2, SW62.2
unnamed: D63.2, SW63.2
unnamed: D64.2, SW64.2
unnamed: D65.2, SW65.2
unnamed: D66.2, SW66.2
unnamed: D67.2, SW67.2
col0: SW1.1, SW2.1, SW3.1, SW4.1, SW5.1, U1.13
col1: SW6.1, SW7.1, SW8.1, SW9.1, SW13.1, U1.12
col2: SW10.1, SW11.1, SW12.1, SW14.1, SW18.1, U1.11
col3: SW15.1, SW16.1, SW17.1, SW19.1, SW28.1, U1.10
col4: SW20.1, SW21.1, SW22.1, SW23.1, SW24.1, SW35.1, U1.9
col5: SW25.1, SW26.1, SW27.1, SW29.1, SW31.1, SW45.1, U1.8
col6: SW32.1, SW33.1, SW34.1, SW36.1, SW37.1, SW50.1, U1.7
col7: SW38.1, SW39.1, SW40.1, SW41.1, SW56.1, U1.6
col8: SW42.1, SW43.1, SW44.1, SW46.1, SW61.1, U1.5
col9: SW47.1, SW48.1, SW49.1, SW51.1, SW66.1, U1.21
col10: SW52.1, SW53.1, SW54.1, SW55.1, SW67.1, U1.22
col11: SW57.1, SW58.1, SW59.1, SW60.1, U1.23
col12: SW62.1, SW63.1, SW64.1, SW65.1, U1.24
row0: D4.1, D13.1, D18.1, D28.1, D35.1, D45.1, D50.1, D56.1, D61.1, D66.1, D67.1, U1.25
row1: D1.1, D6.1, D10.1, D15.1, D20.1, D25.1, D32.1, D38.1, D42.1, D47.1, D52.1, D57.1, D62.1, U1.26
row2: D2.1, D7.1, D11.1, D16.1, D21.1, D26.1, D33.1, D39.1, D43.1, D48.1, D53.1, D58.1, D63.1, U1.27
row3: D3.1, D8.1, D12.1, D17.1, D22.1, D27.1, D34.1, D40.1, D44.1, D49.1, D54.1, D59.1, D64.1, U1.28
row4: D5.1, D9.1, D14.1, D19.1, D23.1, D29.1, D36.1, D41.1, D46.1, D51.1, D55.1, D60.1, D65.1, U1.29
row5: D24.1, D31.1, D37.1, U1.30

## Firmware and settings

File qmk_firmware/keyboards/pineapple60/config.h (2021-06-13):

/*
Copyright 2021 Saoto Tsuchiya

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
You should have received a copy of the GNU General Public License
along with this program.  If not, see <http://www.gnu.org/licenses/>.
*/

#pragma once

#include "config_common.h"

/* USB Device descriptor parameter */
#define VENDOR_ID    0xFEED
#define PRODUCT_ID   0x0000
#define DEVICE_VER   0x0001
#define MANUFACTURER Saoto Tsuchiya
#define PRODUCT      pineapple60

/* key matrix size */
#define MATRIX_ROWS 6
#define MATRIX_COLS 13

/*
 * Keyboard Matrix Assignments
 *
 * Change this to how you wired your keyboard
 * COLS: AVR pins used for columns, left to right
 * ROWS: AVR pins used for rows, top to bottom
 * DIODE_DIRECTION: COL2ROW = COL = Anode (+), ROW = Cathode (-, marked on diode)
 *                  ROW2COL = ROW = Anode (+), COL = Cathode (-, marked on diode)
 *
 */
#define MATRIX_ROW_PINS { C7, D6, B7, B6, B5, E6 }	// DO
#define MATRIX_COL_PINS { C6, D0, D1, D3, B3, B2, B1, F0, F1, F4, F5, F6, F7 } // DI pullup
#define UNUSED_PINS

/* COL2ROW, ROW2COL */
#define DIODE_DIRECTION COL2ROW

/*
 * Split Keyboard specific options, make sure you have 'SPLIT_KEYBOARD = yes' in your rules.mk, and define SOFT_SERIAL_PIN.
 */
#define SOFT_SERIAL_PIN D0  // or D1, D2, D3, E6

//#define BACKLIGHT_PIN B7
//#define BACKLIGHT_LEVELS 3
//#define BACKLIGHT_BREATHING

//#define RGB_DI_PIN E2
//#ifdef RGB_DI_PIN
//#    define RGBLED_NUM 16
//#    define RGBLIGHT_HUE_STEP 8
//#    define RGBLIGHT_SAT_STEP 8
//#    define RGBLIGHT_VAL_STEP 8
//#    define RGBLIGHT_LIMIT_VAL 255 /* The maximum brightness level */
//#    define RGBLIGHT_SLEEP  /* If defined, the RGB lighting will be switched off when the host goes to sleep */
/*== all animations enable ==*/
//#    define RGBLIGHT_ANIMATIONS
/*== or choose animations ==*/
//#    define RGBLIGHT_EFFECT_BREATHING
//#    define RGBLIGHT_EFFECT_RAINBOW_MOOD
//#    define RGBLIGHT_EFFECT_RAINBOW_SWIRL
//#    define RGBLIGHT_EFFECT_SNAKE
//#    define RGBLIGHT_EFFECT_KNIGHT
//#    define RGBLIGHT_EFFECT_CHRISTMAS
//#    define RGBLIGHT_EFFECT_STATIC_GRADIENT
//#    define RGBLIGHT_EFFECT_RGB_TEST
//#    define RGBLIGHT_EFFECT_ALTERNATING
/*== customize breathing effect ==*/
/*==== (DEFAULT) use fixed table instead of exp() and sin() ====*/
//#    define RGBLIGHT_BREATHE_TABLE_SIZE 256      // 256(default) or 128 or 64
/*==== use exp() and sin() ====*/
//#    define RGBLIGHT_EFFECT_BREATHE_CENTER 1.85  // 1 to 2.7
//#    define RGBLIGHT_EFFECT_BREATHE_MAX    255   // 0 to 255
//#endif

/* Debounce reduces chatter (unintended double-presses) - set 0 if debouncing is not needed */
#define DEBOUNCE 5

/* define if matrix has ghost (lacks anti-ghosting diodes) */
//#define MATRIX_HAS_GHOST

/* Mechanical locking support. Use KC_LCAP, KC_LNUM or KC_LSCR instead in keymap */
#define LOCKING_SUPPORT_ENABLE
/* Locking resynchronize hack */
#define LOCKING_RESYNC_ENABLE

/* If defined, GRAVE_ESC will always act as ESC when CTRL is held.
 * This is useful for the Windows task manager shortcut (ctrl+shift+esc).
 */
//#define GRAVE_ESC_CTRL_OVERRIDE

/*
 * Force NKRO
 *
 * Force NKRO (nKey Rollover) to be enabled by default, regardless of the saved
 * state in the bootmagic EEPROM settings. (Note that NKRO must be enabled in the
 * makefile for this to work.)
 *
 * If forced on, NKRO can be disabled via magic key (default = LShift+RShift+N)
 * until the next keyboard reset.
 *
 * NKRO may prevent your keystrokes from being detected in the BIOS, but it is
 * fully operational during normal computer usage.
 *
 * For a less heavy-handed approach, enable NKRO via magic key (LShift+RShift+N)
 * or via bootmagic (hold SPACE+N while plugging in the keyboard). Once set by
 * bootmagic, NKRO mode will always be enabled until it is toggled again during a
 * power-up.
 *
 */
//#define FORCE_NKRO

/*
 * Feature disable options
 *  These options are also useful to firmware size reduction.
 */

/* disable debug print */
//#define NO_DEBUG

/* disable print */
//#define NO_PRINT

/* disable action features */
//#define NO_ACTION_LAYER
//#define NO_ACTION_TAPPING
//#define NO_ACTION_ONESHOT

/* disable these deprecated features by default */
#define NO_ACTION_MACRO
#define NO_ACTION_FUNCTION

/* Bootmagic Lite key configuration */
//#define BOOTMAGIC_LITE_ROW 0
//#define BOOTMAGIC_LITE_COLUMN 0

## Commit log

2021-02-01 Add the KiCad data of p60-2
    [pineapple60.kicad_pcb, pineapple60.sch]
2021-03-06 add a footprint for Kailh switch
2021-06-26 add the pineapple-4 pcb cad data
    [pineapple4.kicad_pcb, pineapple4.sch]
2021-08-19 add namecard KiCAD data
    [namecard.kicad_pcb, namecard.sch]
2021-08-19 add readme.md for KiCAD/namecard1.1/
2026-05-08 add the prototype of p60c

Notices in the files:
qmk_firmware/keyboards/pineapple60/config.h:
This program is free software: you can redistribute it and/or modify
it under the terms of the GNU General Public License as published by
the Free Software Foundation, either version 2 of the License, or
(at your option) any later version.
